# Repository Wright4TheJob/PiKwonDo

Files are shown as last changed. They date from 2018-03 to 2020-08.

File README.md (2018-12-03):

# PiKwonDo
A Raspberry Pi-based system for scoring TaeKwonDo sparring matches.

# Goals
The goal of this project is to create an inexpensive system for scoring TaeKwonDo sparring. This system is intended to be small and easily modified to suit the needs of individual Dojangs. The system is currently designed for electronic scoring manually triggered by corner judges.

Phase 1 of the judging system will use judge triggers connected by wires to the central controller. Phase 2 is intended to use wireless judge trigger systems or mobile phone connectivity.

While the system is designed to mimic expensive World TaeKwonDo-approved systems, it is not certified for official tournament use.

# Status


Bill of Materials:

The project is under alpha development. Software has been developed but has yet to be tested with the hardware. Electronics are designed for single-sided PCB routing and have all completed initial design but have not been tested yet. Cases are designed for 3D printing. Hardware and software folders have individual README files with more particular statuses and todo items.

All design files and software are provided "as-is." Any stable releases will be bundled for easy download, but this does not guarantee suitability for your particular setup.

# Software
The judging software and UI is written in python and QT. A dedicated thread scans the status of judge controller buttons. Game logic and UI are run as the primary thread.
<!--Wireless versions of the software may use Twisted to create a local server.-->

# Electronics
Controllers use shift registers to store and sequentially read out the values of the buttons in each controller. Judge controllers have 10 buttons and the timer controller has 5. PCBs are designed for single-side milling, with traces no smaller than 0.4mm and trace gaps of 0.3mm. Through-hole components are used for hand soldering and occasional jumper wires are used.

# Hardware
The system is designed and tested on a Raspberry Pi 3B+. Physical wiring uses phone jacks and standard 4-conductor phone cables for data communication to judging triggers. Cases are designed for 3D printing and modeled in Solidworks.
<!--Future iterations may investigate the viability of using the Raspberry Pi Zero W.-->

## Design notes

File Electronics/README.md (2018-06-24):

# Electronics
The PiKwonDo is made of four different electrical boards bundled into three unique and connected elements: the processing core, the PiKwonDoHAT, the timer control board, and the judge control board.

All circuits and PCBs are modeled in KiCAD. PCBs are minimal complexity necessary. Boards are intended to be single-sided and capable of being milled on a home circuit board router.

# Processing Core
The core processing unit of the PiKwonDo is a Raspberry Pi. The system is being tested on a Raspberry Pi 3B+.

# PiKwonDoHAT
The PiKwonDoHAT board mounts to the Raspberry Pi and provides the GPIO interface to the RJ12 ports and external boxes. This board contains no logic, simply provides an I/O adapter.

# Peripheral Boxes
All the peripheral boxes (timer and judge boxes), use shift registers to store the button states and sequentially report buttons states to the processor when requested. This method reduces the number of data lines to the central processor and de-couples the number of data lines from the number of buttons per peripheral.

An LED is lighted by the shift pin of the shift register and will illuminate whenever the central processor is querying the state of the buttons.

## Timer
The timer control board contains 5 buttons: three to control the round timing (Start, Pause, Reset), and two penalty buttons (Red and Blue). A single shift register is used to output the state of these 5 buttons.

## Judge
The judge box board contains 10 buttons corresponding to point values of 1 through 5 for both red and blue. Two shift registers passing data in series are used to store the values of all 10 buttons.

# Status
Circuit diagrams have been completed and initial PCB layout and trace routing is done.

## TODO
* Finalize button positions on timer controller.
* Finalize BOM and component selection.
* Update component footprints to reflect BOM.
* Update trace size and spacing to ensure manufacturability.

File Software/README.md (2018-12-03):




# Software
The PiKwonDo software uses two primary processing threads to control 1) game logic and GUI and 2) scanning buttons and driving GPIO data flow. Software is written in Python and uses PiQT5 for GUI elements.

# Dependencies
* PyQT5
* GPIO

# Installation
Delete the RPi folder in Software to direct the python installtion to the global GPIO library present on the Raspberry Pi. If testing or modifying the software on a desktop computer, the RPi folder mimics the GPIO library and allows the software to run.

# Startup
To start the PiKwonDo software, navigate to the Software folder in the terminal and launch the PyKwonDo.py file using Python 3:
```
$ python3 PyKwonDo.py
```

# Status
Initial software class structure and functionality are in place. Interpretation of the button states is currently rudimentary. GUI is functional.

# Documentation
All documentation is generated using Sphinx and deployed on GihubPages [here]( https://wright4thejob.github.io/PiKwonDo/build/html/index.html). New code commits with correct docstrings can update the documentation by running ```$ make html``` from PiKwonDo/Software/docs.

## TODO
* Add check for system parameters to allow non-Raspberry Pi code testing
* Complete GPIO scanning code and test with hardware.
* Unit test combinations of judge signals.
* Create automated installation script.

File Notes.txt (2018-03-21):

Notes:
Send judge signal over 3 bits using 8-3 binary encoder

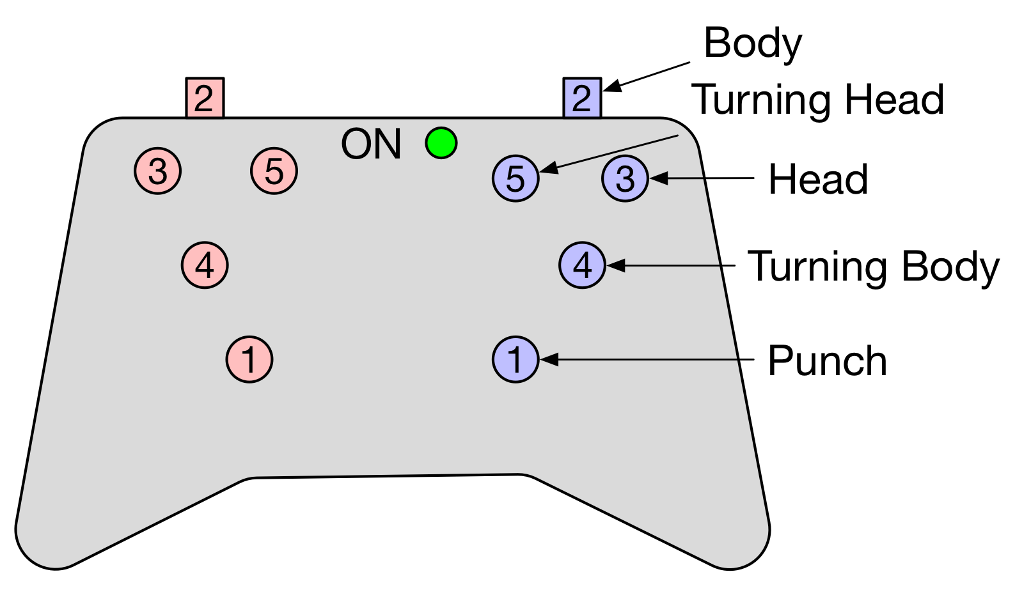
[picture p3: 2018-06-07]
Hardware/Judge Box/Button Layouts/ButtonDiagonal.png

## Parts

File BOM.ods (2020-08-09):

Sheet: PiKwonDo
 | System | Description | Part # | Manufacturer | Unit Price | Quantity | Total | Link
1 | Main Box | HAT |  | In-house | $11.55 | 1 | $11.55
2 |  | Raspberry Pi Zero |  |  | $5.00 | 1 | $5.00 | https://www.adafruit.com/product/3775?src=raspberrypi
3 |  | SD Card | 467-SDSDQAB-008G | SanDisk | $7.59 | 1 | $7.59 | https://www.mouser.com/ProductDetail/SanDisk/SDSDQAB-008G
4 |  | Power Cable | 1995 |  | $7.50 | 1 | $7.50 | https://www.adafruit.com/product/1995
5 |  | Header | 474-PRT-14275 |  | $0.95 | 1 | $0.95 | https://www.mouser.com/ProductDetail/SparkFun/PRT-14275
6 |  | Case Front | JudgeCaseFront | 3D Printed | $0.00 | 1 | $0.00
7 |  | Case Back | JudgeCaseBack | 3D Printed | $0.00 | 1 | $0.00
8 | Judging | Judge Box |  | In-house | $11.43 | 3 | $34.28
9 | Timing | Timer Box |  | In-house | $7.31 | 1 | $7.31
10 | Connection | Long Cable |  |  | $6.97 | 2 | $13.94
11 |  | Short Cable |  |  | $5.44 | 2 | $10.88
 |  |  |  |  |  | Total: | $99.00

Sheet: Judge Trigger Box
 | System | Description | Use | Manufacturer | Unit Price | Part # | Quantity | Total | Package | Link
1 | Buttons | Front Switch | Point values 1,3, 4, and 5 | Apem | $0.56 | MHPS2285V | 8 | $4.48 |  | https://www.mouser.com/ProductDetail/Apem/MHPS2285V?qs=sGAEpiMZZMvxtGF7dlGNpukRB9Cmt7zIMn5KtKQiwQo%3d
2 |  | Trigger Switch | 2 point trigger | E-Switch | $0.72 | LC1258OASP | 2 | $1.44 |  | https://www.mouser.com/ProductDetail/612-LC1258OASP
3 | PCB | PCB | Circuit board | JLCPCB | $0.83 |  | 1 | $0.83 |  | https://www.aliexpress.com/item/85042-Free-shipping-FR4-PCB-Single-Side-Copper-Clad-plate-DIY-PCB-Kit-Laminate-Circuit-Board/32658447865.html
4 | Memory | Shift Register | Data Storage | TI | $0.47 | SN74HC165N | 2 | $0.94 |  | https://www.mouser.com/ProductDetail/Texas-Instruments/SN74HC165N
5 | Diodes | Green LED | D1 (LED) | LiteOn | $0.12 | 859-LTL-4231N | 1 | $0.12 | T-1 3mm | https://www.mouser.com/ProductDetail/Lite-On/LTL-4231N
6 |  | Schottky Diode | D2 | Rectron | $0.10 | 583-FM5817 | 1 | $0.10 | SMA | https://www.mouser.com/ProductDetail/Rectron/FM5817-W
7 |  | Zener Diode | D3, D4, D5 | Rectron | $0.08 | 583-ZMM5232B | 3 | $0.24 | SOD-80C | https://www.mouser.com/ProductDetail/Rectron/ZMM5232B
8 | Capacitors | 470 pF Capacitor | C4, C5, C6 | Vishay | $0.08 | 885012208073 | 3 | $0.24 | SMD 1206 in | https://www.mouser.com/ProductDetail/Vishay-Vitramon/VJ0603A271JXACW1BC
9 |  | 1 uF Capacitor | C1, C2, C3 | Vishay | $0.10 | VJ1206Y105MXJTW1BC | 1 | $0.10 | SMD 1210 in | https://www.mouser.com/ProductDetail/Vishay-Vitramon/VJ1210V106ZXJTW1BC
10 | Resistors | 47 kOhm Resistor Network | RN1 and RN2 | Xicon | $0.25 | 264-47K-RC | 2 | $0.50 | SIP 6 | https://www.mouser.com/ProductDetail/Xicon/264-47K-RC?qs=sGAEpiMZZMvrmc6UYKmaNY74CgudZSh69je1RFoxttc%3d
11 |  | 470 Ohm Resistor | R2 and R3 | Vishay | $0.10 | 71-RCG1206470RJNEA | 2 | $0.20 | SMD 1206 in | https://www.mouser.com/ProductDetail/Vishay-Draloric/RCG1206470RJNEA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
12 |  | 10 Ohm Resistor | R4 | Ohmite | $0.10 | 588-AS12J10R0ET | 1 | $0.10 | SMD 1206 in | https://www.mouser.com/ProductDetail/Ohmite/AS12J10R0ET
13 |  | 68 Ohm Resistor | R1 | Vishay | $0.10 | 71-CRCW1206-68-E3 | 1 | $0.10 | SMD 1206 in | https://www.mouser.com/ProductDetail/Vishay/CRCW120668R0FKEA?qs=sGAEpiMZZMtlubZbdhIBIG0PxkvhMYcAMeHHOyUrHXU%3d
14 | I/O | RJ11 Port | Data Socket | Amphenol | $0.64 | RJE03-166-0110 | 1 | $0.64 |  | https://www.mouser.com/ProductDetail/Amphenol-Commercial-Products/RJE03-166-0110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
15 | Case | Case Front |  | 3D Printed | $1.02 | JudgeCaseFront | 1 | $1.02
16 |  | Case Back |  | 3D Printed | $0.00 | JudgeCaseBack | 1 | $0.00
17 |  | Button Cover |  | 3D Printed | $0.03 | ButtonCover | 8 | $0.22
18 |  | Trigger Cover |  | 3D Printed | $0.08 | TriggerCover | 2 | $0.15
 |  |  |  |  |  |  | Total: | $11.43

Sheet: Timer
 | System | Description | Schematic Number | Manufacturer | Unit Price | Part # Mouser | Part # Digikey | Quantity | Total | Package | Link
1 | Buttons | Front Switch | Point values 1,3, 4, and 5 | Apem | $0.56 | MHPS2285V |  | 5 | $2.80 |  | https://www.mouser.com/ProductDetail/Apem/MHPS2285V?qs=sGAEpiMZZMvxtGF7dlGNpukRB9Cmt7zIMn5KtKQiwQo%3d
2 | PCB | PCB | Circuit board | JLCPCB | $1.14 |  |  | 1 | $1.14 |  | https://www.mouser.com/ProductDetail/MG-Chemicals/521?qs=sGAEpiMZZMvAiOZiEFBkewg52Uv5EwqlDCdUaM0T7yM%3d
3 | Memory | Shift Register | U2 | TI | $0.47 | SN74HC165N |  | 1 | $0.47 |  | https://www.aliexpress.com/item/85042-Free-shipping-FR4-PCB-Single-Side-Copper-Clad-plate-DIY-PCB-Kit-Laminate-Circuit-Board/32658447865.html
4 | Diodes | Schottky Diode | D1 | Rectron | $0.10 | 583-FM5817 |  | 1 | $0.10 | DO-214AC | https://www.mouser.com/ProductDetail/Rectron/FM5817-W
5 |  | Green LED | D2 (LED) | LiteOn | $0.12 | 859-LTL-4231N |  | 1 | $0.12 | T-1 3mm | https://www.mouser.com/ProductDetail/Lite-On/LTL-4231N
6 |  | Zener Diode 5V | D3 | Rectron | $0.08 | 583-ZMM5232B |  | 1 | $0.08 | SOD-80C | https://www.mouser.com/ProductDetail/Rectron/ZMM5232B
7 |  | Zener Diode 3.3V | D4 | Nexperia | $0.19 |  | 1727-7754-1-ND | 1 | $0.19 | SOD-123-2 | https://www.mouser.com/ProductDetail/Diodes-Incorporated/MMSZ5226B-7-F
8 | Capacitors | 1 uF Capacitor | C1, C2 | Vishay | $0.13 | 77-VJ1206Y105MXJTBC |  | 2 | $0.26 | SMD 1206 in | https://www.mouser.com/ProductDetail/Vishay-Vitramon/VJ1206Y105MXJTW1BC
9 |  | 470 pF Capacitor | C3 | Wurth | $0.12 | 710-885012208073 |  | 3 | $0.36 | SMD 1210 in | https://www.mouser.com/ProductDetail/Wurth-Electronics/885012208073
10 | Resistors | 47 kOhm Resistor Network | RN1 | Xicon | $0.25 | 264-47K-RC |  | 1 | $0.25 | SIP 6 | https://www.mouser.com/ProductDetail/Xicon/264-47K-RC?qs=sGAEpiMZZMvrmc6UYKmaNY74CgudZSh69je1RFoxttc%3d
11 |  | 470 Ohm Resistor | R2-R4 | Vishay | $0.10 | 71-RCG1206470RJNEA |  | 3 | $0.30 | SMD 1206 in | https://www.mouser.com/ProductDetail/Vishay-Draloric/RCG1206470RJNEA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
12 |  | 10 Ohm Resistor | R5 | Ohmite | $0.10 |  | RNCP1206FTD10R0CT-ND | 1 | $0.10 | SMD 1206 in | https://www.mouser.com/ProductDetail/Ohmite/AS12J10R0ET
13 |  | 100 Ohm Resistor | R1 | TE | $0.10 | 667-ERJ-8ENF95R3V |  | 1 | $0.10 | SMD 1206 in | https://www.mouser.com/ProductDetail/TE-Connectivity-Holsworthy/CRGP1206F100R
14 | I/O | RJ11 Port | Data Socket | Molex | $0.78 | 538-95009-7641 |  | 1 | $0.78 |  | https://www.mouser.com/ProductDetail/Molex/95009-7641
 |  | Logic Level Shifter | U1 | Microtel | $0.12 | MIC5504-3.3YM5-TR |  | 1 | $0.12 | SC-70-5 or SOT-23-5 | https://www.mouser.com/ProductDetail/Microchip-Technology-Micrel/MIC5504-33YM5-TR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
15 | Case | Case Front |  | 3D Printed | $0.00 | JudgeCaseFront |  | 1 | $0.00
16 |  | Case Back |  | 3D Printed | $0.00 | JudgeCaseBack |  | 1 | $0.00
17 |  | Button Cover |  | 3D Printed | $0.03 | ButtonCover |  | 5 | $0.14
 |  |  |  |  |  |  |  | Total: | $7.31

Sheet: HAT
 | System | Description | Use | Manufacturer | Unit Price | Part # Mouser | Part # Digikey | Quantity | Total | Package | Link
1 |  | RJ11 Port | Data Socket | Amphenol | $0.64 | RJE03-166-0110 |  | 4 | $2.56 |  | https://www.mouser.com/ProductDetail/Amphenol-Commercial-Products/RJE03-166-0110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
2 |  | PCB | Circuit board | JLCPCB | $0.40 |  |  | 1 | $0.40 |  | https://www.aliexpress.com/item/5-pc-7-10CM-Single-Side-Circuit-Board-Copper-Clad-Plate-Laminate-Universal-PCB-Circuit-Board/32799673259.html
3 |  | Pin Header | CN1 |  | $2.55 | 517-929975-01-20 |  | 1 | $2.55 |  | https://www.mouser.com/ProductDetail/3M-Electronic-Solutions-Division/929975-01-20
4 | Capacitors | 10 nF Capacitor | C1-C4 | Wurth | $0.11 |  | 732-8093-1-ND | 4 | $0.44 | SMD 1206 in | https://www.mouser.com/ProductDetail/Wurth-Electronics/885012208026
5 |  | 470 pF Capacitor | C5-C12 | Wurth | $0.12 | 710-885012208073 |  | 8 | $0.96 | SMD 1206 in | https://www.mouser.com/ProductDetail/Wurth-Electronics/885012208073
6 | Resistor | 470 Ohm Resistor | R3, R6, R9, R12 | Vishay | $0.10 | 71-RCG1206470RJNEA |  | 4 | $0.40 | SMD 1206 in | https://www.mouser.com/ProductDetail/Vishay-Draloric/RCG1206470RJNEA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
 |  | 10 Ohm Resistor | R1,R2,R4,R5,R7,R8,R10,R11 | Ohmite | $0.10 |  | RNCP1206FTD10R0CT-ND | 8 | $0.80 | SMD 1206 in | https://www.mouser.com/ProductDetail/Ohmite/AS12J10R0ET
7 | Diodes | Zener Diode 5V | D1 | Rectron | $0.08 | 583-ZMM5232B |  | 1 | $0.08 | SOD-80C or SOD-323 | https://www.mouser.com/ProductDetail/Rectron/ZMM5232B
8 |  | Zener Diode 3.3V | D2-D9 | Diodes Inc. | $0.19 | 621-MMSZ5226B-F |  | 8 | $1.52 | SOD-123-2 | https://www.mouser.com/ProductDetail/Diodes-Incorporated/MMSZ5226B-7-F
9 |  | Buffer |  | TI | $0.46 | 595-SN74LV1T34DBVR |  | 4 | $1.84 | SC-70-5 or SOT-23-5 | https://www.mouser.com/ProductDetail/Texas-Instruments/SN74LV1T34DBVR
 |  |  |  |  |  |  |  | Total: | $11.55

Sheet: Printed Part Costs
Part | Weight [g] | Unit Cost | 1 kg Spool Cost: | $30.00
Button Cover | 0.93 | $0.03
Trigger Cover | 2.5 | $0.08
Judge Box Top | 34.08 | $1.02
Judge Box Bottom
Timer Box Top
Timer Box Bottom
Main Box Top
Main Box Bottom

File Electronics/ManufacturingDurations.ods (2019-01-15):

 | Duration | Quantity | Total
Leveling | 00:15:00 | 1 | 0.01042
PCB Traces | 00:27:20 | 1 | 0.01898
PCB Drilling | 00:16:10 | 1 | 0.01123
PCB Drill/Mill | 00:01:57 | 1 | 0.00135
PCB Edges | 00:05:00 | 1 | 0.00347
Tool Changes | 00:01:00 | 2 | 0.00139
Mill Total: |  |  | 67.45 | Minutes
Mill Time Cost: |  |  | $10.00 | $/hr
Mill Cost: |  |  | $11.24
Soldering: | 01:00:00 | 1 | 0.04167
Solder Total: |  |  | 60 | Minutes
Solder Time Cost: |  |  | $25.00 | $/hr
Solder Cost: |  |  | $25.00
Total Cost: |  |  | $36.24

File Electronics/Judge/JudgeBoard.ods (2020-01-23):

Reference | Quantity | Quant | Value | Footprint | Datasheet
C1 C2 C3 | 3 | 27 | 1uF | Capacitor_SMD:C_1206_3216Metric_Pad1.42x1.75mm_HandSolder
C4 C5 C6 | 3 | 27 | 470pF | Capacitor_SMD:C_1206_3216Metric_Pad1.42x1.75mm_HandSolder
D1 | 1 | 9 | LED | LED_THT:LED_D3.0mm_Spread
D2 | 1 | 9 | D_Schottky | Diodes_SMD:D_SMA_Handsoldering
D3 | 1 | 9 | 3.3V | Diode_SMD:D_1206_3216Metric_Pad1.42x1.75mm_HandSolder
D5 | 1 | 9 | 5V | Diodes_SMD:SOD-80C
J1 | 1 | 9 | RJ10 | Local_lib:RJ14 | ~
R1 R3 R5 | 3 | 27 | 470 | Resistor_SMD:R_1206_3216Metric_Pad1.42x1.75mm_HandSolder
R2 | 1 | 9 | 10 | Resistor_SMD:R_1206_3216Metric_Pad1.42x1.75mm_HandSolder
R4 | 1 | 9 | 100 | Resistor_SMD:R_1206_3216Metric_Pad1.42x1.75mm_HandSolder
RN1 RN2 | 2 | 18 | 47k | Resistor_THT:R_Array_SIP6
S1 | 1 | 9 | R1 | Buttons_Switches_THT:MHPS2285V
S10 | 1 | 9 | B5 | Buttons_Switches_THT:MHPS2285V
S2 | 1 | 9 | R3 | Buttons_Switches_THT:MHPS2285V
S3 | 1 | 9 | R5 | Buttons_Switches_THT:MHPS2285V
S4 | 1 | 9 | B2 | PiKwonDo:Switch-SPDT
S5 | 1 | 9 | B4 | Buttons_Switches_THT:MHPS2285V
S6 | 1 | 9 | R2 | PiKwonDo:Switch-SPDT
S7 | 1 | 9 | R4 | Buttons_Switches_THT:MHPS2285V
S8 | 1 | 9 | B1 | Buttons_Switches_THT:MHPS2285V
S9 | 1 | 9 | B3 | Buttons_Switches_THT:MHPS2285V
U1 U2 | 2 | 18 | 74HC165 | Housings_DIP:DIP-16_W7.62mm_LongPads
U3 | 1 | 9 | MIC5504-3.3YM5 | Package_TO_SOT_SMD:SOT-23-5 | http://ww1.microchip.com/downloads/en/DeviceDoc/MIC550X.pdf

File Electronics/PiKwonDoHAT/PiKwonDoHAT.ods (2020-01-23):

Reference | Quantity | Value | Footprint | Datasheet
C2 C1 C4 C3 | 4 | 10nF | Capacitor_SMD:C_1206_3216Metric_Pad1.42x1.75mm_HandSolder
C6 C5 C8 C7 C10 C9 C12 C11 | 8 | 470pF | Capacitor_SMD:C_1206_3216Metric_Pad1.42x1.75mm_HandSolder
D1 | 1 | 5V | Diodes_SMD:D_SOD-323_HandSoldering
D2 D3 D4 D5 D6 D7 D8 D9 | 8 | 3.3V | Diode_SMD:D_SOD-123
J1 J2 J3 J4 | 4 | RJ10 | Local_lib:RJ14 | ~
J5 | 1 | Conn_02x20_Odd_Even | Connector_PinSocket_2.54mm:PinSocket_2x20_P2.54mm_Vertical | ~
R1 R2 R5 R7 R10 R4 R8 R11 | 8 | 10 | Resistors_SMD:R_1206_HandSoldering
R3 R6 R9 R12 | 4 | 470 | Resistors_SMD:R_1206_HandSoldering
U1 U2 U3 U4 | 4 | 74LV1T34 | TO_SOT_Packages_SMD:SOT-23-5_HandSoldering

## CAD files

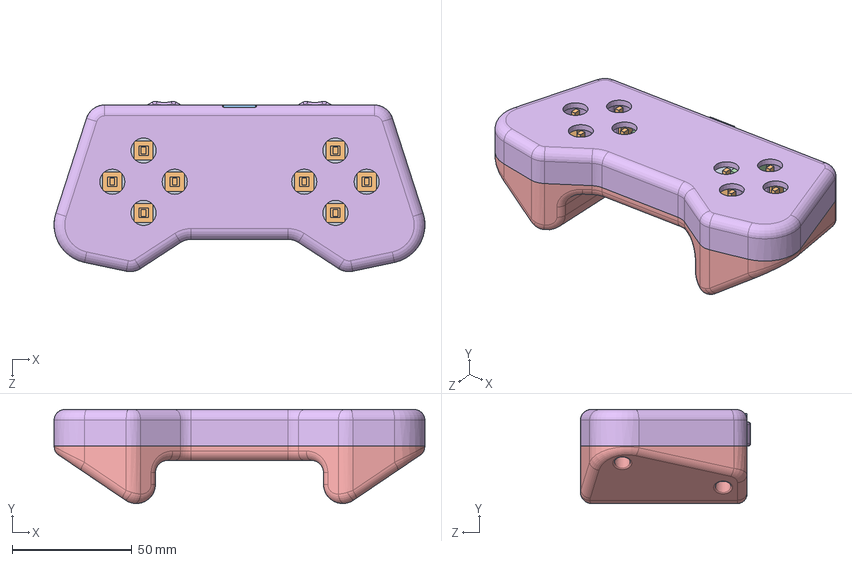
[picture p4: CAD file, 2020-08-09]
Hardware/Judge Box/JudgeController.SLDASM
154.6 x 39.2 x 71.0 mm
JudgePCB
PushButton x 8
RJ12Socket
TriggerButton x 2
JudgeEnclosureBack
JudgeEnclosureFront

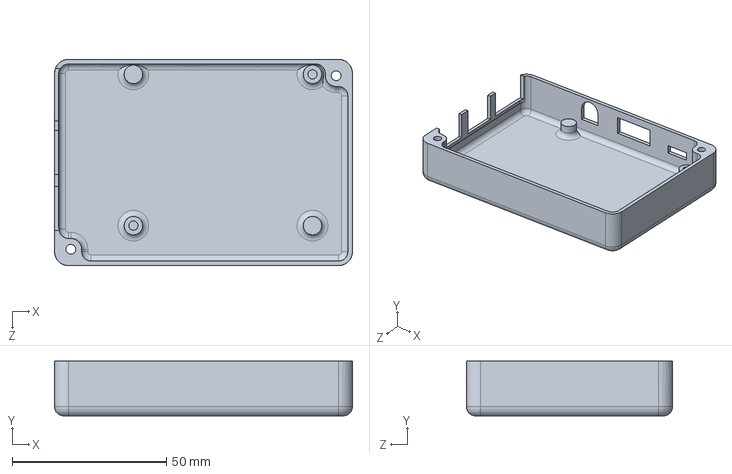
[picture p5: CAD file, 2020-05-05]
Hardware/Main Box/MainBoxCaseBottom.SLDPRT
96.5 x 17.8 x 66.8 mm

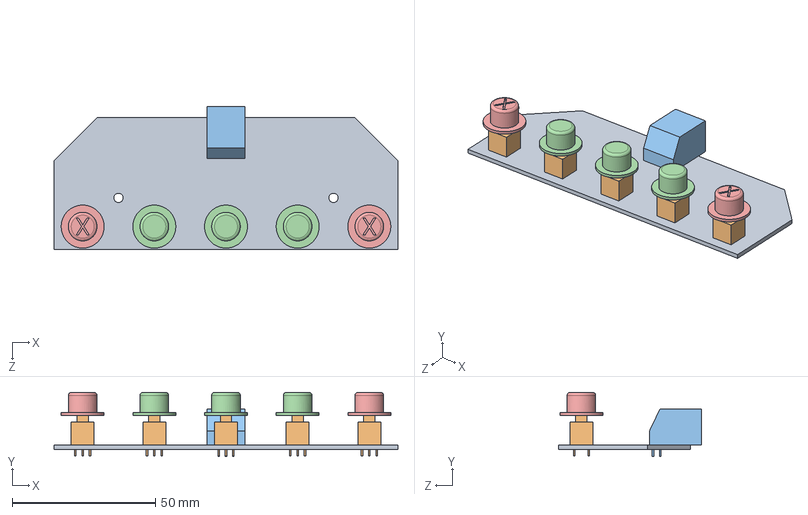
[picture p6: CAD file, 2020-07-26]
Hardware/Timer Box/TimerBoard.SLDASM
120.0 x 22.4 x 49.9 mm
TimerPCB
PushButton x 5
RJ12Socket
TopButtonCoverPlain x 3
TopButtonCoverX x 2

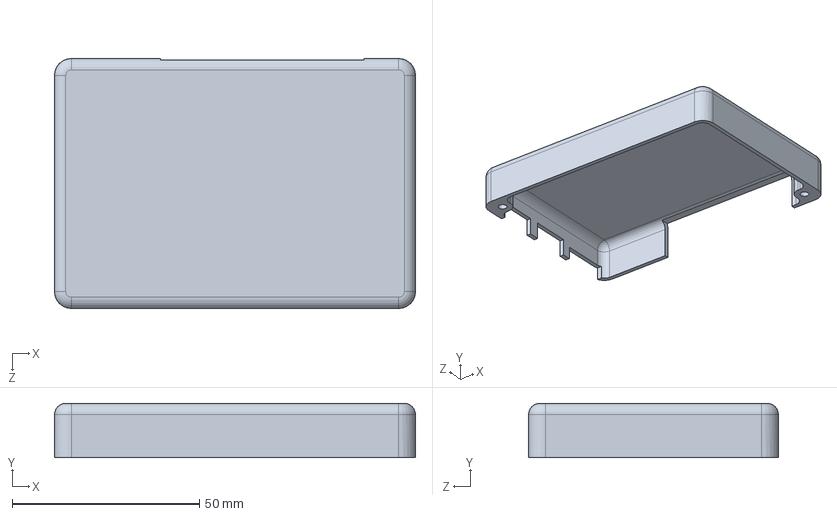
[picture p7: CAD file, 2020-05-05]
Hardware/Main Box/MainBoxCaseTop.SLDPRT
96.5 x 14.5 x 66.8 mm

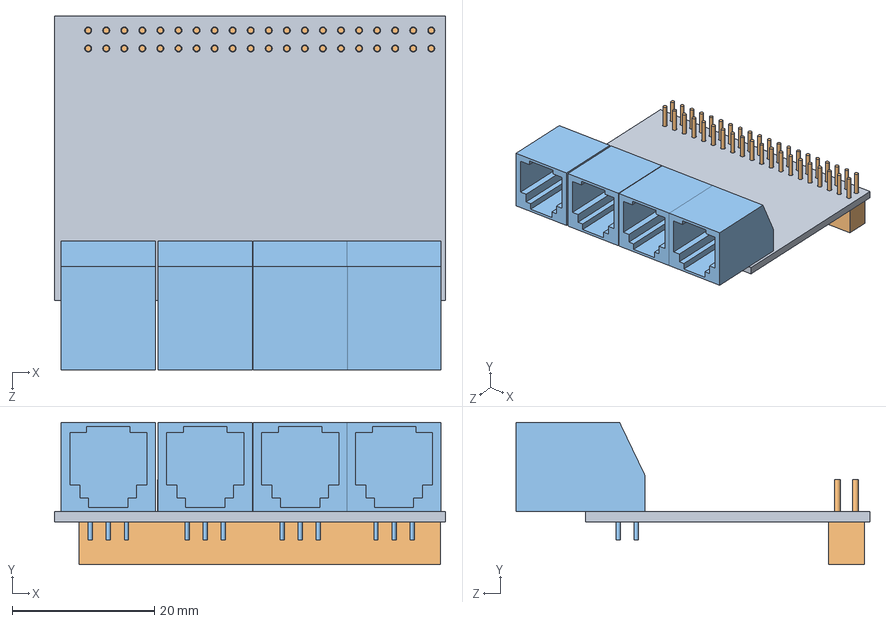
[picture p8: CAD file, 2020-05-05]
Hardware/Main Box/PiAdapterBoard.SLDASM
55.0 x 20.0 x 49.7 mm
HAT-PCB
PinHeader
RJ12Socket x 4

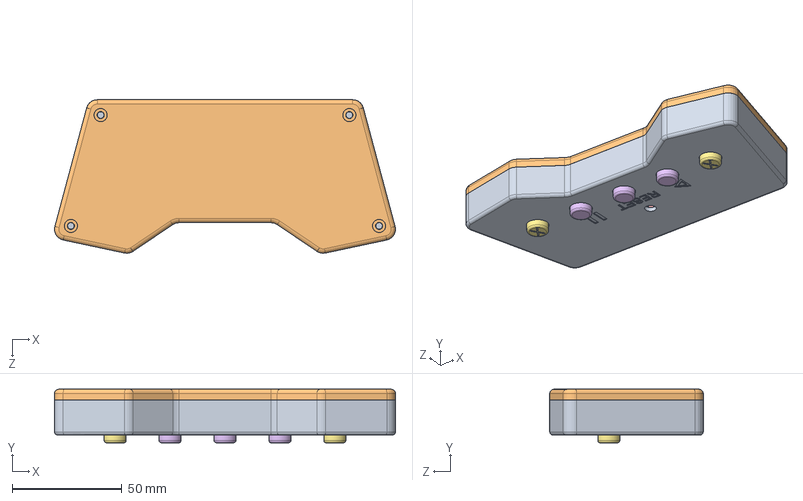
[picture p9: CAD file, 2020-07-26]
Hardware/Timer Box/TimerBox.SLDASM
155.3 x 24.4 x 69.9 mm
TimerBoxCaseTop
TimerPCB
PushButton x 5
RJ12Socket
TopButtonCoverPlain x 3
TopButtonCoverX x 2

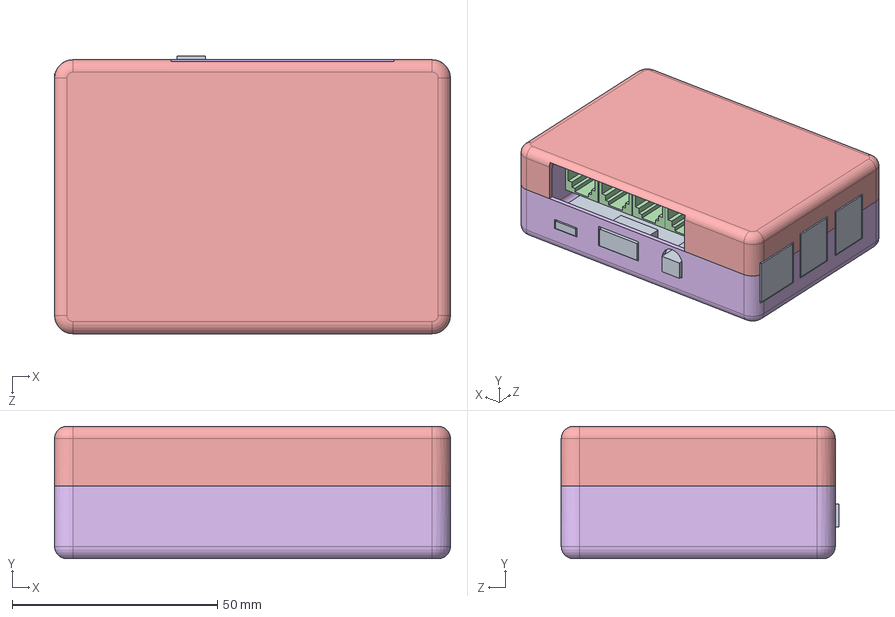
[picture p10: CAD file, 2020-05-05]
Hardware/Main Box/MainBox.SLDASM
96.5 x 32.3 x 67.7 mm
RaspberryPi3B+
HAT-PCB
PinHeader
RJ12Socket x 4
MainBoxCaseTop
MainBoxCaseBottom

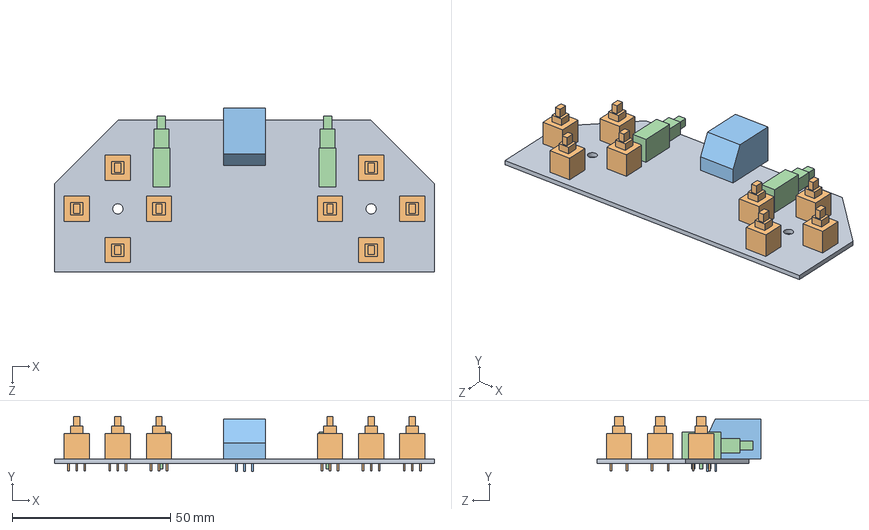
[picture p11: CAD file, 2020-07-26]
Hardware/Judge Box/JudgeBoard.SLDASM
120.0 x 17.4 x 51.9 mm
JudgePCB
PushButton x 8
RJ12Socket
TriggerButton x 2

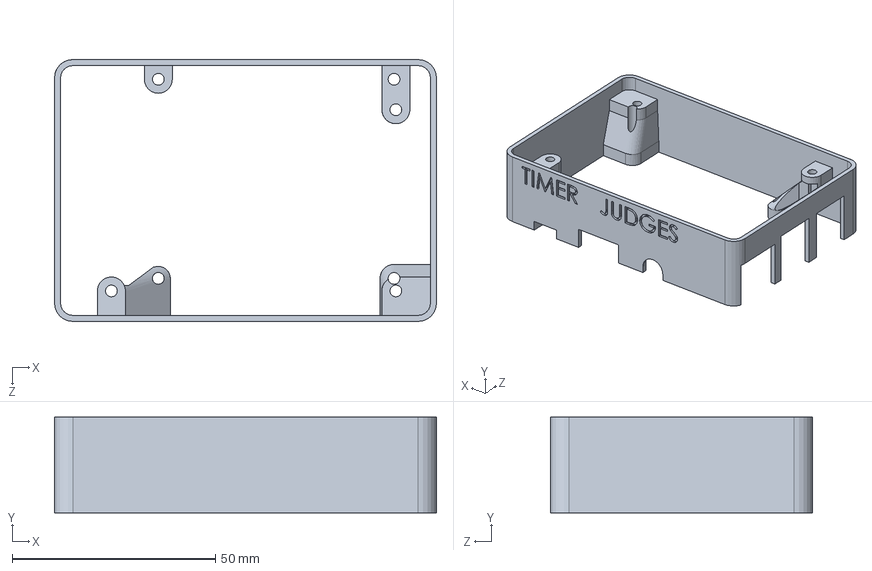
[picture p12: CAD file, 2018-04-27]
Hardware/Main Box/MainBoxCaseCenter.SLDPRT
94.0 x 23.5 x 64.4 mm

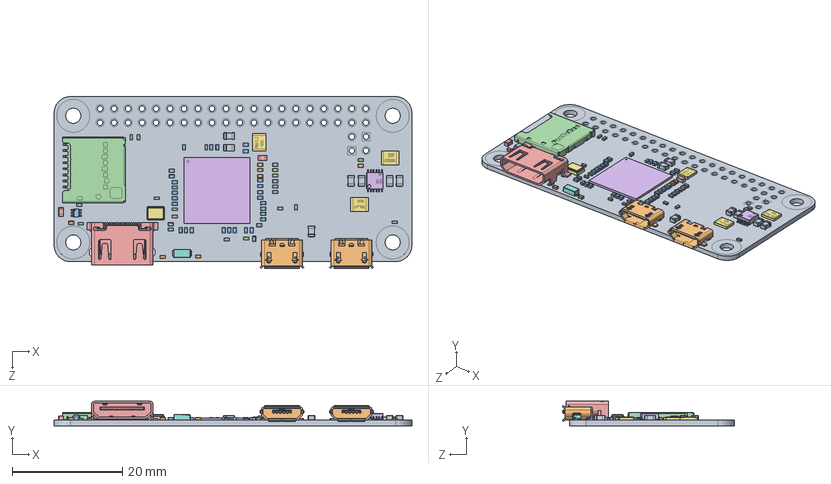
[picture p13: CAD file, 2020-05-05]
Hardware/Main Box/Raspberry Pi Zero/RapberryPiZero.SLDASM
65.0 x 4.45 x 31.2 mm
Raspberry_pizero_PCB
Micro USB_input_female (short)-SMT x 2
0204 - Capacitor x 34
0204- Resistor x 17
CAP-0306 x 2
Raspberry_pizero_BCM2835 with VC4
Crystal 3.4x2.4mm
32,768 Khz Crystal
0805- Capacitor x 7
0204 - Capacitor Brown x 8
6-Pin SOT
micro sd molex
hdmi type C
Voltage Regulator 3x3mm 12-Pin
1210 inductor x 3

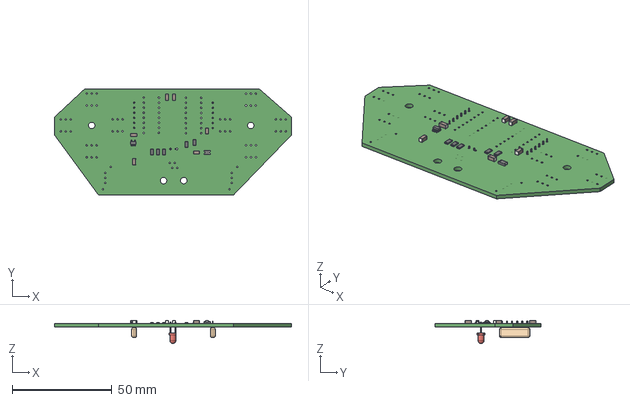
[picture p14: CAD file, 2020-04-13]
Electronics/Judge/JudgeBoard.step
119.0 x 53.0 x 11.6 mm

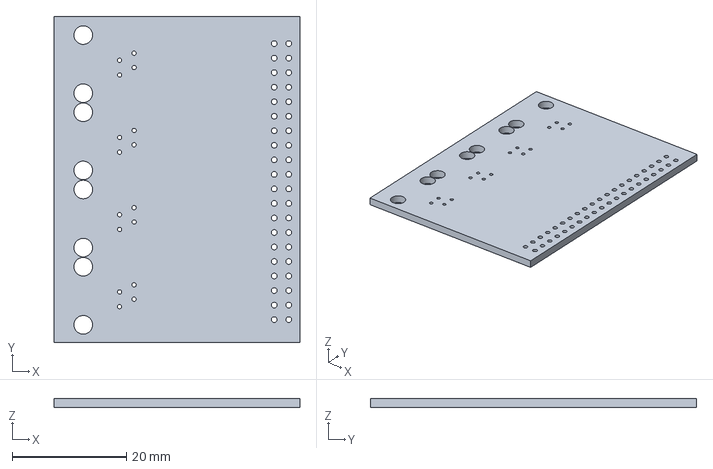
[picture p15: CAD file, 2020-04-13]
Electronics/PiKwonDoHAT/PiKwonDoHAT.step
43.0 x 57.0 x 1.60 mm

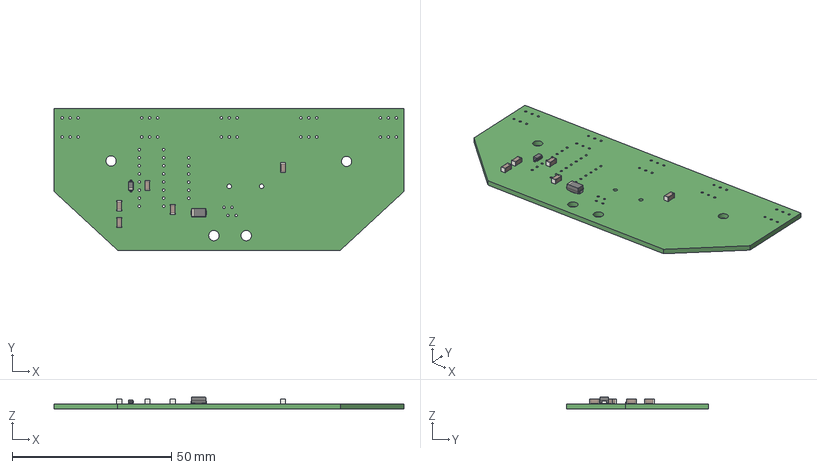
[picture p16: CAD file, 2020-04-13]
Electronics/Timer/Timer.step
110.0 x 44.5 x 3.87 mm

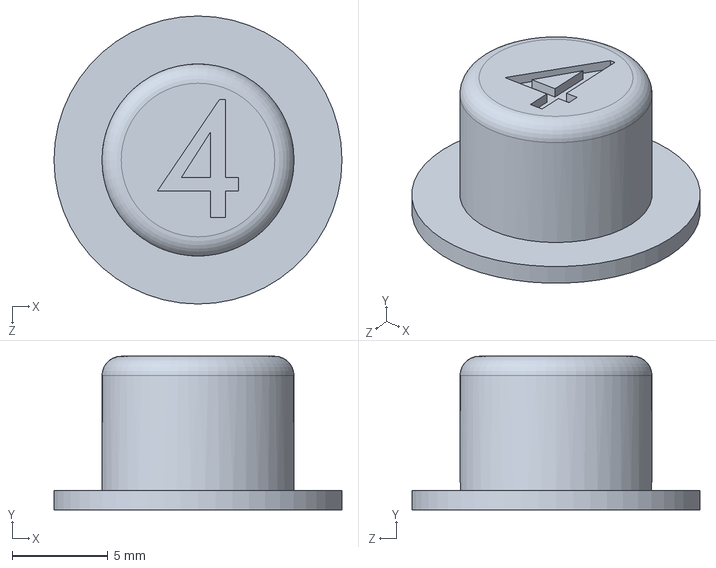
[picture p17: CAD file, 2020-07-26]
Hardware/Common Components/TopButtonCover4.SLDPRT
15.0 x 8.00 x 15.0 mm

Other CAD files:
Hardware/Main Box/Raspberry Pi Zero/32,768 Khz Crystal.SLDPRT
Hardware/Common Components/TriggerButton.SLDPRT
Hardware/Judge Box/JudgeEnclosureBackSolid.3MF
Hardware/Main Box/Raspberry Pi Zero/hdmi type C.SLDPRT
Hardware/Common Components/Dip8Socket.SLDPRT
Hardware/Common Components/PushButton.SLDPRT
Hardware/Common Components/RJ12Socket.SLDPRT
Hardware/Common Components/RaspberryPi3B+.SLDPRT
Hardware/Common Components/TopButtonCover1.SLDPRT
Hardware/Common Components/TopButtonCover1.STL
Hardware/Common Components/TopButtonCover2.SLDPRT
Hardware/Common Components/TopButtonCover3.SLDPRT
Hardware/Common Components/TopButtonCover3.STL
Hardware/Common Components/TopButtonCover4.STL
Hardware/Common Components/TopButtonCover5.SLDPRT
Hardware/Common Components/TopButtonCover5.STL
Hardware/Common Components/TopButtonCoverPlain.SLDPRT
Hardware/Common Components/TopButtonCoverX.SLDPRT
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

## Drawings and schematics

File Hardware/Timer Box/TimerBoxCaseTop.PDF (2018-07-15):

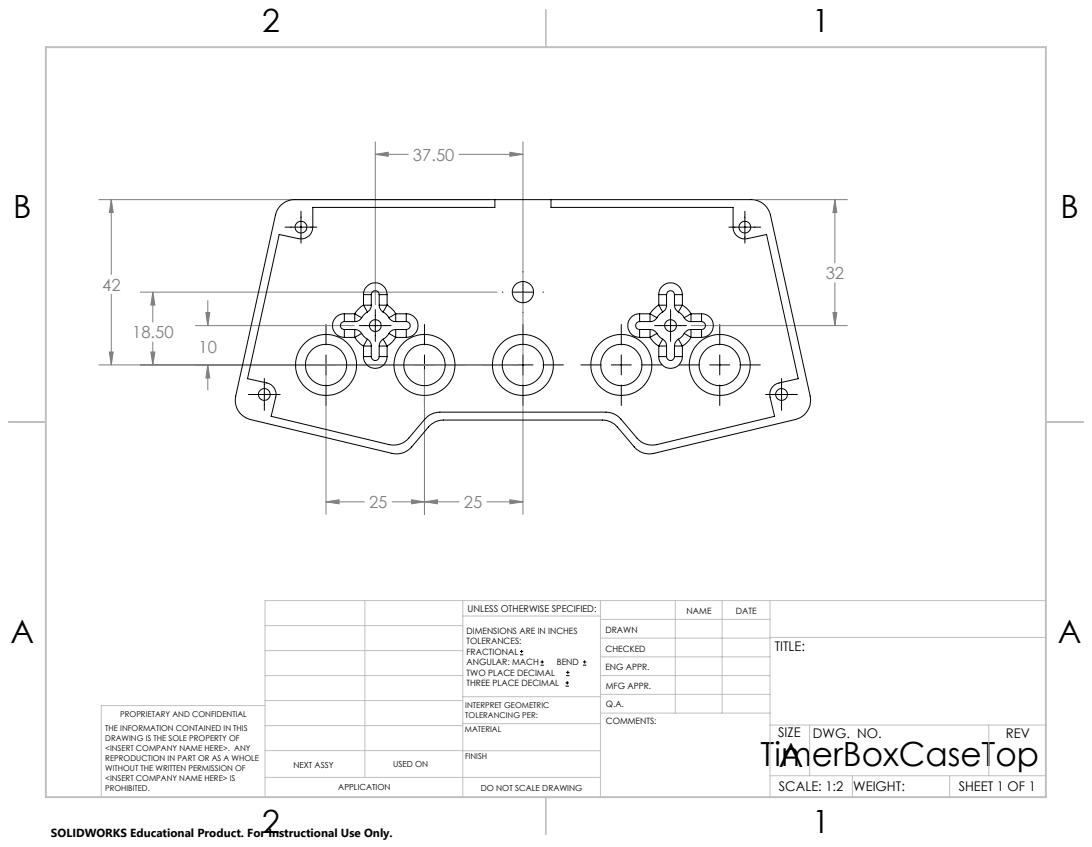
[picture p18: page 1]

UNLESS OTHERWISE SPECIFIED: | | NAME | DATE
DIMENSIONS ARE IN INCHES TOLERANCES: FRACTIONAL ANGULAR: MACH BEND TWO PLACE DECIMAL THREE PLACE DECIMAL | DRAWN

CHECKED | | | TITLE:

ENG APPR.
MFG APPR.

INTERPRET GEOMETRIC TOLERANCING PER: | Q.A.
MATERIAL | TimerBoxCaseTop | SIZE A | DWG. NO. | REV

PROPRIETARY AND CONFIDENTIAL
THE INFORMATION CONTAINED IN THIS
DRAWING IS THE SOLE PROPERTY OF
<INSERT COMPANY NAME HERE>. ANY
REPRODUCTION IN PART OR AS A WHOLE
WITHOUT THE WRITTEN PERMISSION OF
<INSERT COMPANY NAME HERE> IS
PROHIBITED.

NEXT ASSY | USED ON | FINISH

APPLICATION | DO NOT SCALE DRAWING | | SCALE: 1:2 | WEIGHT: | SHEET 1 OF 1

SOLIDWORKS Educational Product. For Instructional Use Only.

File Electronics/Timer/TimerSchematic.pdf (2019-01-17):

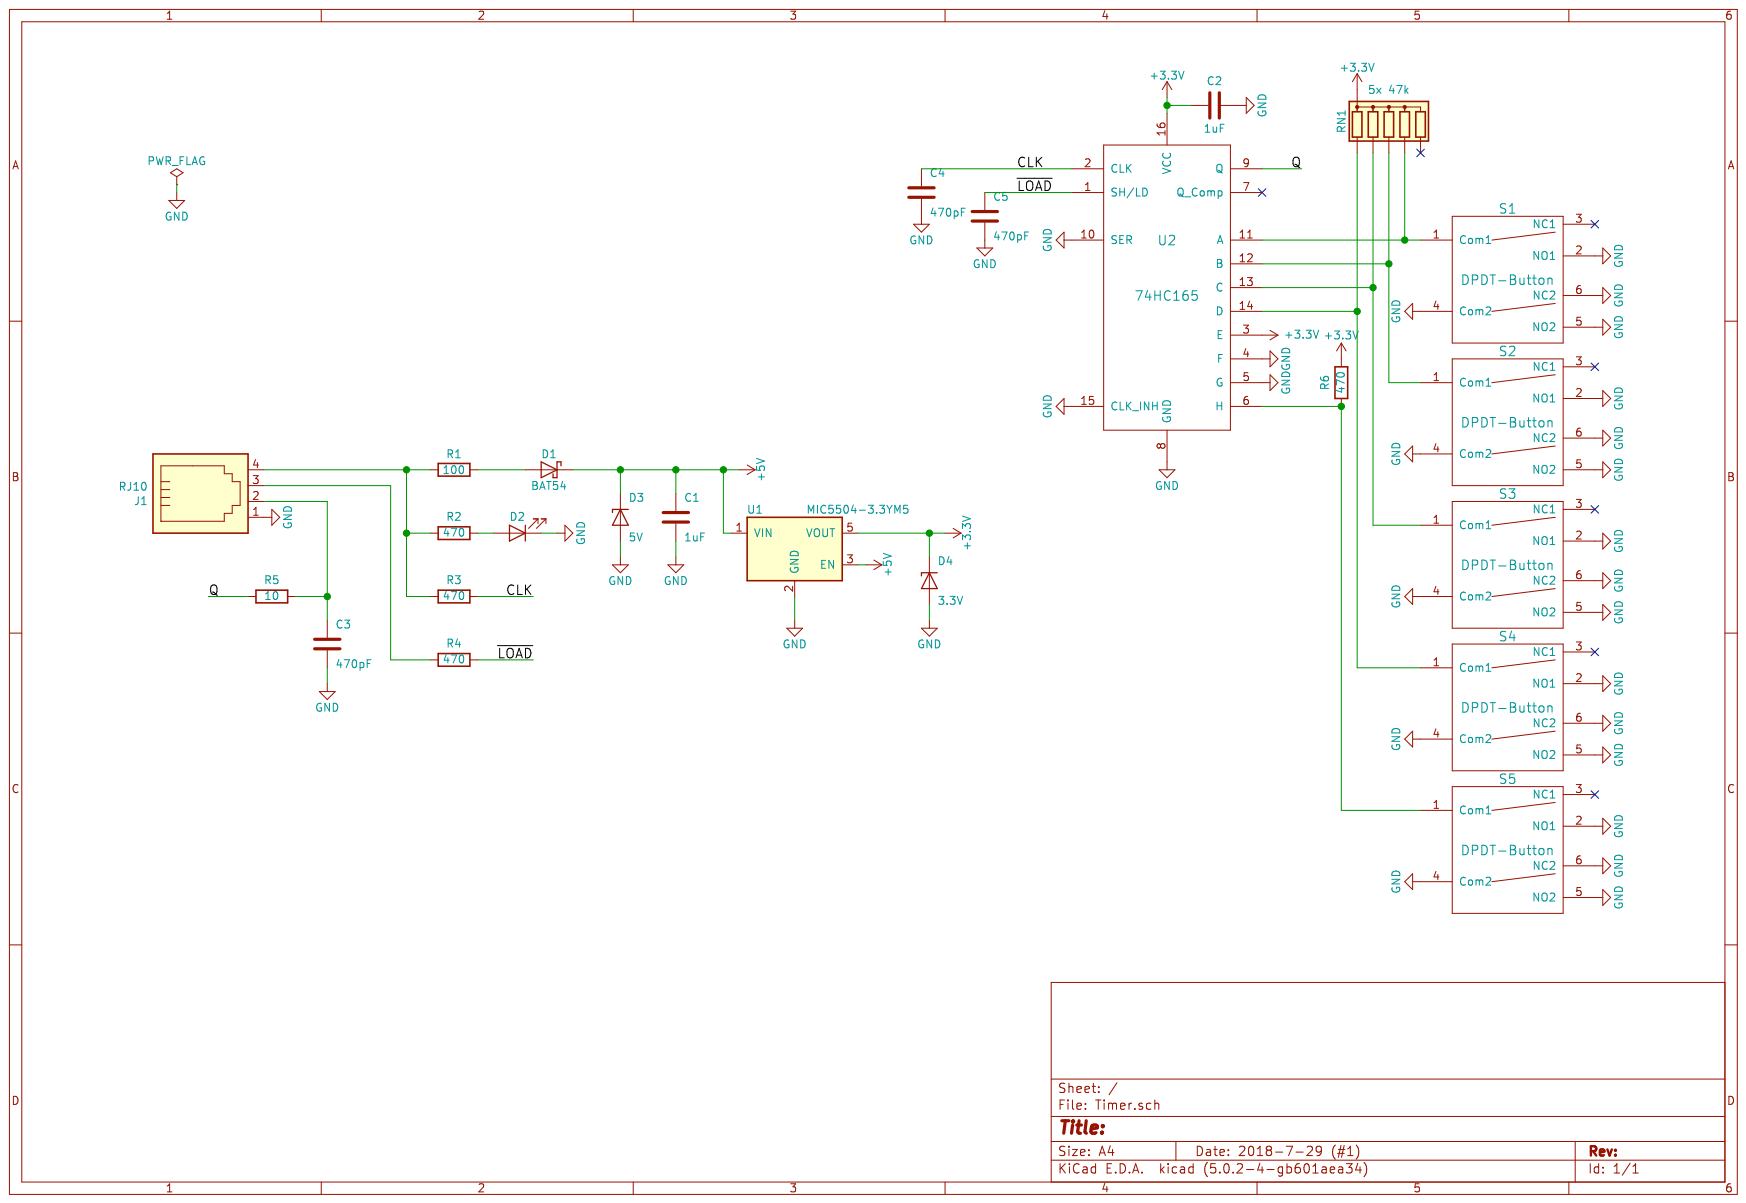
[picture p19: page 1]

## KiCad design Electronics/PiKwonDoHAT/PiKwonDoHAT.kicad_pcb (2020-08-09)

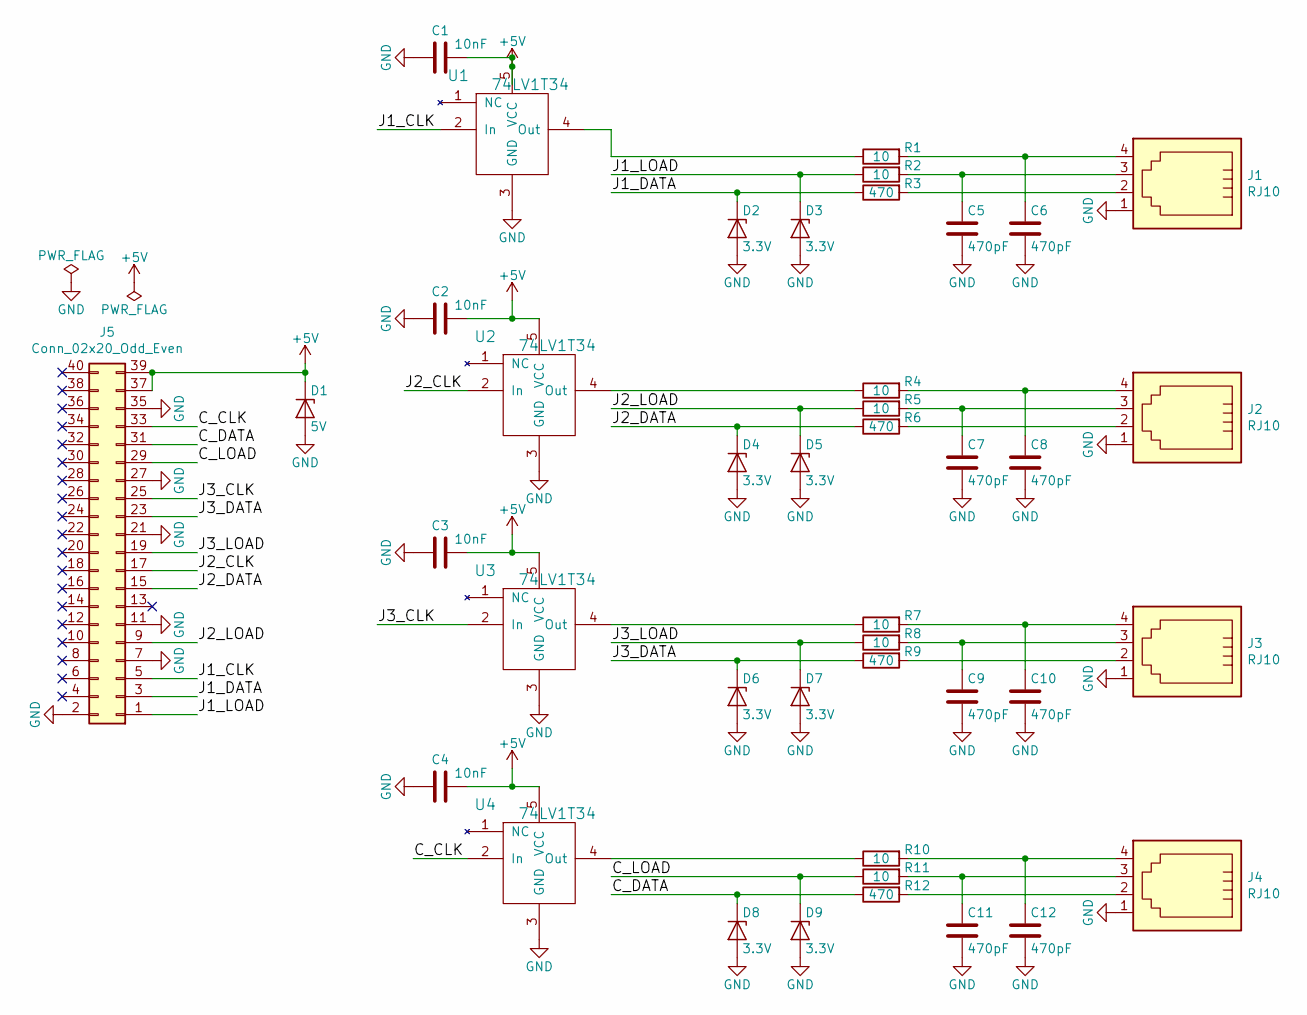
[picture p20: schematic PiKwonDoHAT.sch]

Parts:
C1, C2, C3, C4: 10nF; C_1206_3216Metric_Pad1.42x1.75mm_HandSolder
C5, C6, C7, C8, C9, C10, C11, C12: 470pF; C_1206_3216Metric_Pad1.42x1.75mm_HandSolder
D1: 5V; D_SOD-123
D2, D3, D4, D5, D6, D7, D8, D9: 3.3V; D_SOD-123
J1, J2, J3, J4: RJ10; RJ14
J5: Conn_02x20_Odd_Even; PinSocket_2x20_P2.54mm_Vertical
R1, R2, R4, R5, R7, R8, R10, R11: 10; R_1206_HandSoldering
R3, R6, R9, R12: 470; R_1206_HandSoldering
U1, U2, U3, U4: 74LV1T34; SOT-23-5_HandSoldering

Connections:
+5V: C1.1, C2.1, C3.1, C4.1, D1.1 (K), J5.37, J5.39, U1.5 (VCC), U2.5 (VCC), U3.5 (VCC), U4.5 (VCC)
/C_CLK: J5.33, U4.2 (In)
/C_DATA: D8.1 (K), J5.31, R12.1
/C_LOAD: D9.1 (K), J5.29, R11.1
/J1_CLK: J5.5, U1.2 (In)
/J1_DATA: D2.1 (K), J5.3, R3.1
/J1_LOAD: D3.1 (K), J5.1, R2.1
/J2_CLK: J5.17, U2.2 (In)
/J2_DATA: D4.1 (K), J5.15, R6.1
/J2_LOAD: D5.1 (K), J5.9, R5.1
/J3_CLK: J5.25, U3.2 (In)
/J3_DATA: D6.1 (K), J5.23, R9.1
/J3_LOAD: D7.1 (K), J5.19, R8.1
GND: C1.2, C2.2, C3.2, C4.2, C5.2, C6.2, C7.2, C8.2, C9.2, C10.2, C11.2, C12.2, D1.2 (A), D2.2 (A), D3.2 (A), D4.2 (A), D5.2 (A), D6.2 (A), D7.2 (A), D8.2 (A), D9.2 (A), J1.1, J2.1, J3.1, J4.1, J5.2, J5.7, J5.11, J5.21, J5.27, J5.35, U1.3 (GND), U2.3 (GND), U3.3 (GND), U4.3 (GND)
unnamed: C5.1, J1.3, R2.2
unnamed: C6.1, J1.4, R1.2
unnamed: C7.1, J2.3, R5.2
unnamed: C8.1, J2.4, R4.2
unnamed: C9.1, J3.3, R8.2
unnamed: C10.1, J3.4, R7.2
unnamed: C11.1, J4.3, R11.2
unnamed: C12.1, J4.4, R10.2
unnamed: J1.2, R3.2
unnamed: J2.2, R6.2
unnamed: J3.2, R9.2
unnamed: J4.2, R12.2
unnamed: R1.1, U1.4 (Out)
unnamed: R4.1, U2.4 (Out)
unnamed: R7.1, U3.4 (Out)
unnamed: R10.1, U4.4 (Out)

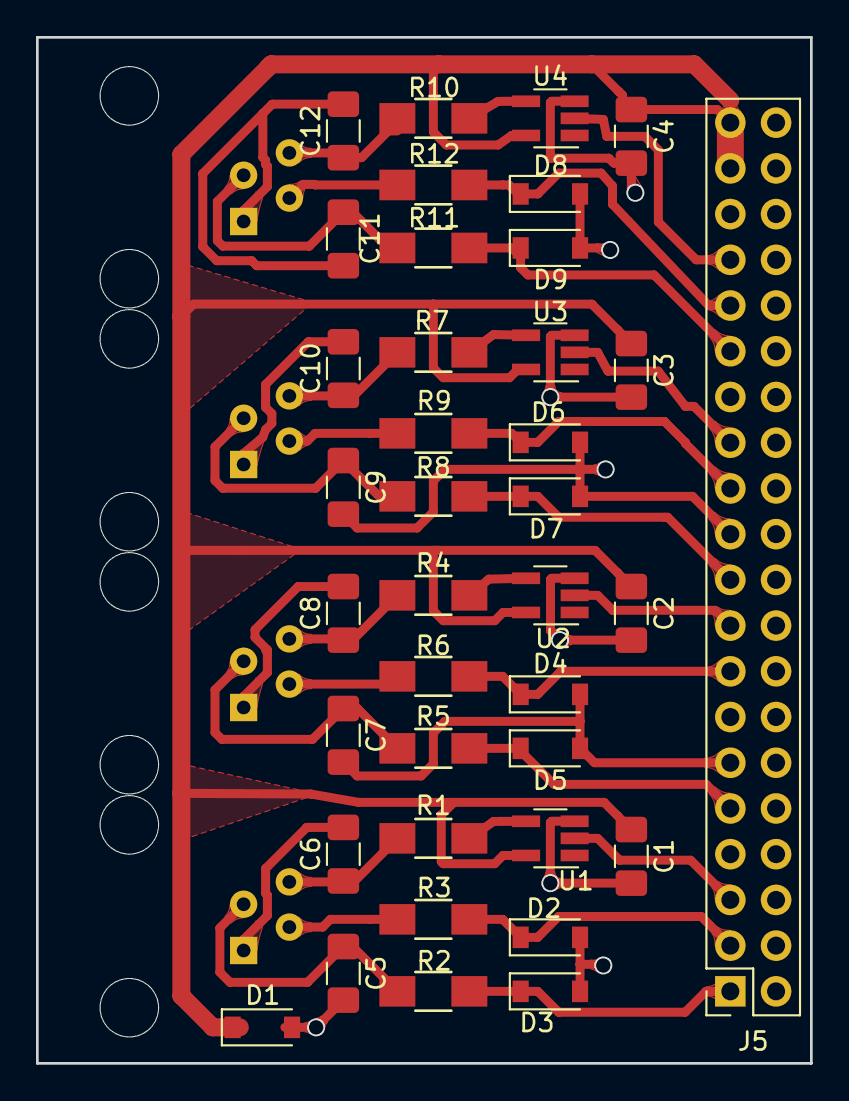
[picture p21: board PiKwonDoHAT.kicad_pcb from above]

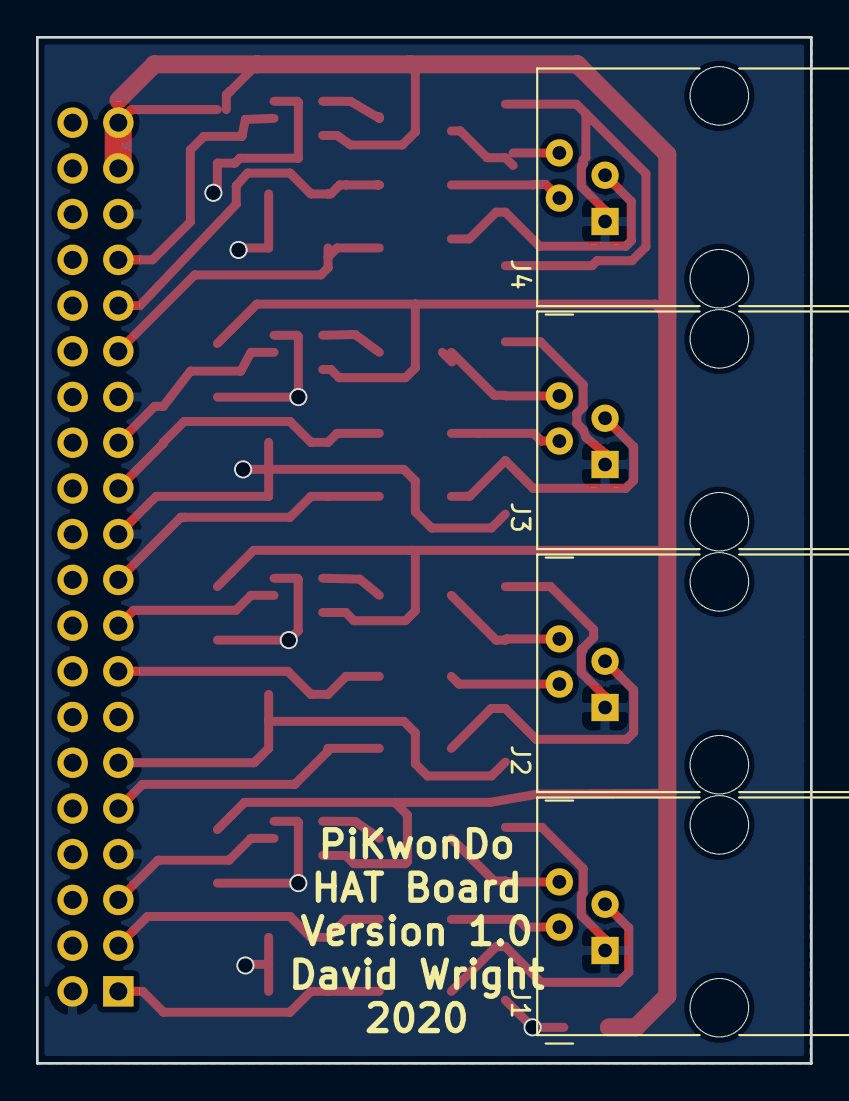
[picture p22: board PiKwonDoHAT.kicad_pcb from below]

Board: 2 copper layers, 43.0 x 57.0 mm, 42 parts (4 on the bottom side), 30 nets.

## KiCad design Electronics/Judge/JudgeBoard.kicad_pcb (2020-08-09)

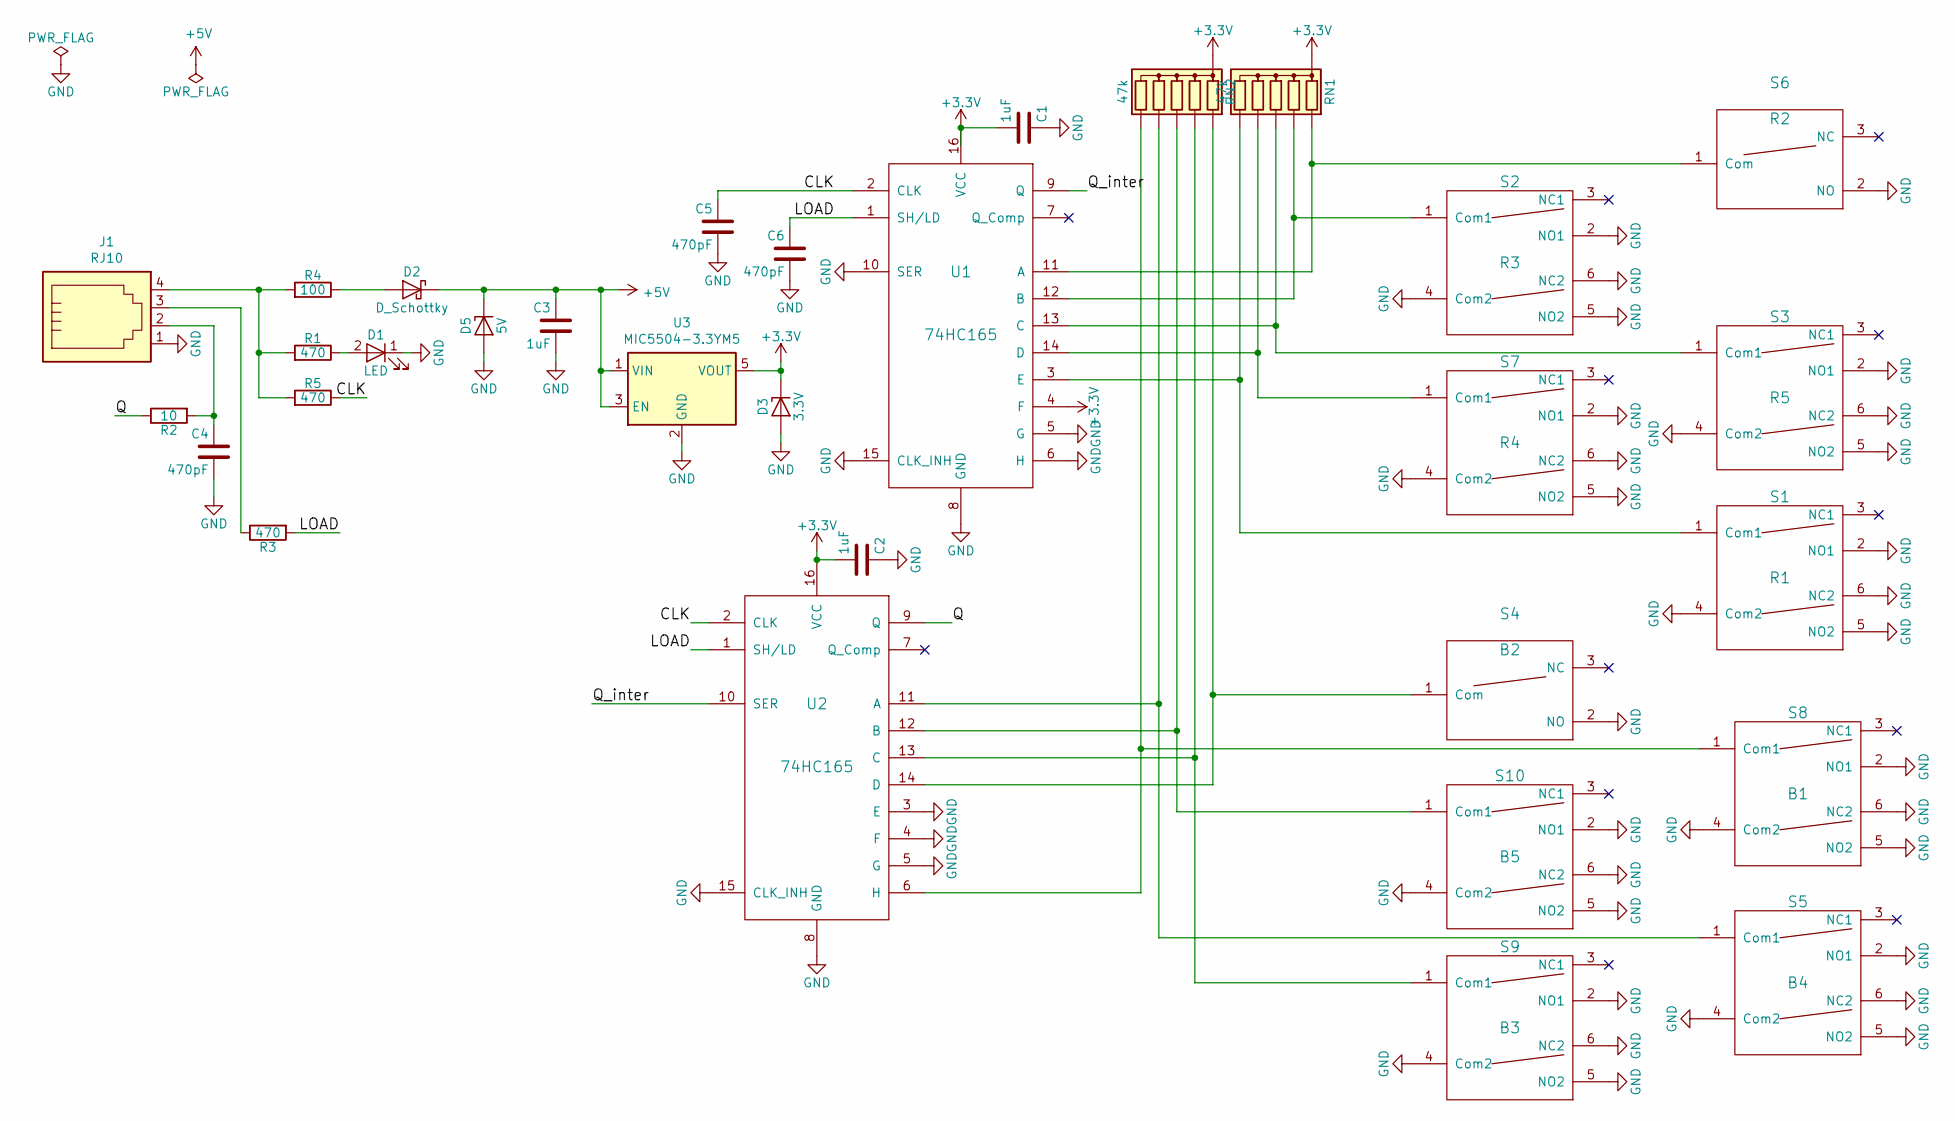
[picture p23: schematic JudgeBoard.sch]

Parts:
C1, C2, C3: 1uF; C_1206_3216Metric_Pad1.42x1.75mm_HandSolder
C4, C5, C6: 470pF; C_1206_3216Metric_Pad1.42x1.75mm_HandSolder
D1: LED; LED_D3.0mm_Spread
D2: D_Schottky; D_SMA_Handsoldering
D3: 3.3V; D_1206_3216Metric_Pad1.42x1.75mm_HandSolder
D5: 5V; SOD-80C
J1: RJ10; RJ14
R1, R3, R5: 470; R_1206_3216Metric_Pad1.42x1.75mm_HandSolder
R2: 10; R_1206_3216Metric_Pad1.42x1.75mm_HandSolder
R4: 100; R_1206_3216Metric_Pad1.42x1.75mm_HandSolder
RN1, RN2: 47k; R_Array_SIP6
S1: R1; MHPS2285V
S2: R3; MHPS2285V
S3: R5; MHPS2285V
S4: B2; Switch-SPDT
S5: B4; MHPS2285V
S6: R2; Switch-SPDT
S7: R4; MHPS2285V
S8: B1; MHPS2285V
S9: B3; MHPS2285V
S10: B5; MHPS2285V
U1, U2: 74HC165; DIP-16_W7.62mm_LongPads
U3: MIC5504-3.3YM5; SOT-23-5

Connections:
+3V3: C1.2, C2.2, D3.1 (K), RN1.1 (common), RN2.1 (common), U1.4 (F), U1.16 (VCC), U2.16 (VCC), U3.5 (VOUT)
+5V: C3.1, D2.1 (K), D5.1 (K), U3.1 (VIN), U3.3 (EN)
/CLK: C5.1, R5.1, U1.2 (CLK), U2.2 (CLK)
/LOAD: C6.1, R3.2, U1.1 (SH/LD), U2.1 (SH/LD)
/Q: R2.1, U2.9 (Q)
/Q_inter: U1.9 (Q), U2.10 (SER)
GND: C1.1, C2.1, C3.2, C4.2, C5.2, C6.2, D1.1 (K), D3.2 (A), D5.2 (A), J1.1, S1.2 (NO1), S1.4 (Com2), S1.5 (NO2), S1.6 (NC2), S2.2 (NO1), S2.4 (Com2), S2.5 (NO2), S2.6 (NC2), S3.2 (NO1), S3.4 (Com2), S3.5 (NO2), S3.6 (NC2), S4.2 (NO), S5.2 (NO1), S5.4 (Com2), S5.5 (NO2), S5.6 (NC2), S6.2 (NO), S7.2 (NO1), S7.4 (Com2), S7.5 (NO2), S7.6 (NC2), S8.2 (NO1), S8.4 (Com2), S8.5 (NO2), S8.6 (NC2), S9.2 (NO1), S9.4 (Com2), S9.5 (NO2), S9.6 (NC2), S10.2 (NO1), S10.4 (Com2), S10.5 (NO2), S10.6 (NC2), U1.5 (G), U1.6 (H), U1.8 (GND), U1.10 (SER), U1.15 (CLK_INH), U2.3 (E), U2.4 (F), U2.5 (G), U2.8 (GND), U2.15 (CLK_INH), U3.2 (GND)
unnamed: C4.1, J1.2, R2.2
unnamed: D1.2 (A), R1.1
unnamed: D2.2 (A), R4.1
unnamed: J1.3, R3.1
unnamed: J1.4, R1.2, R4.2, R5.2
unnamed: RN1.2 (R1), S6.1 (Com), U1.11 (A)
unnamed: RN1.3 (R2), S2.1 (Com1), U1.12 (B)
unnamed: RN1.4 (R3), S3.1 (Com1), U1.13 (C)
unnamed: RN1.5 (R4), S7.1 (Com1), U1.14 (D)
unnamed: RN1.6 (R5), S1.1 (Com1), U1.3 (E)
unnamed: RN2.2 (R1), S4.1 (Com), U2.14 (D)
unnamed: RN2.3 (R2), S9.1 (Com1), U2.13 (C)
unnamed: RN2.4 (R3), S10.1 (Com1), U2.12 (B)
unnamed: RN2.5 (R4), S5.1 (Com1), U2.11 (A)
unnamed: RN2.6 (R5), S8.1 (Com1), U2.6 (H)

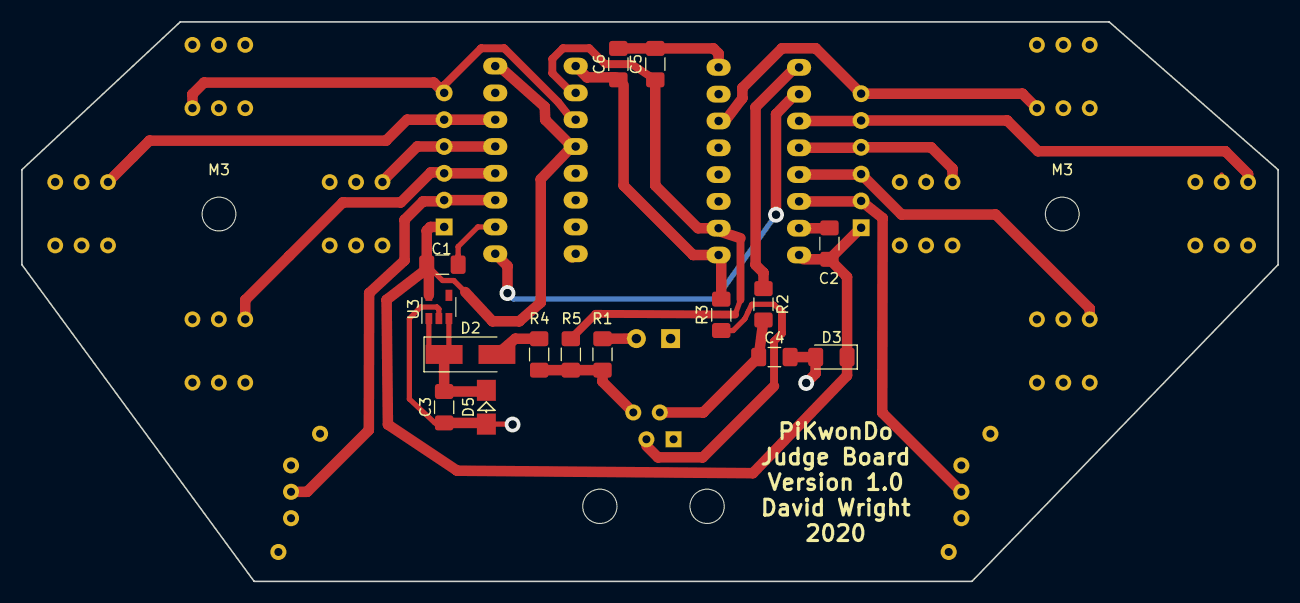
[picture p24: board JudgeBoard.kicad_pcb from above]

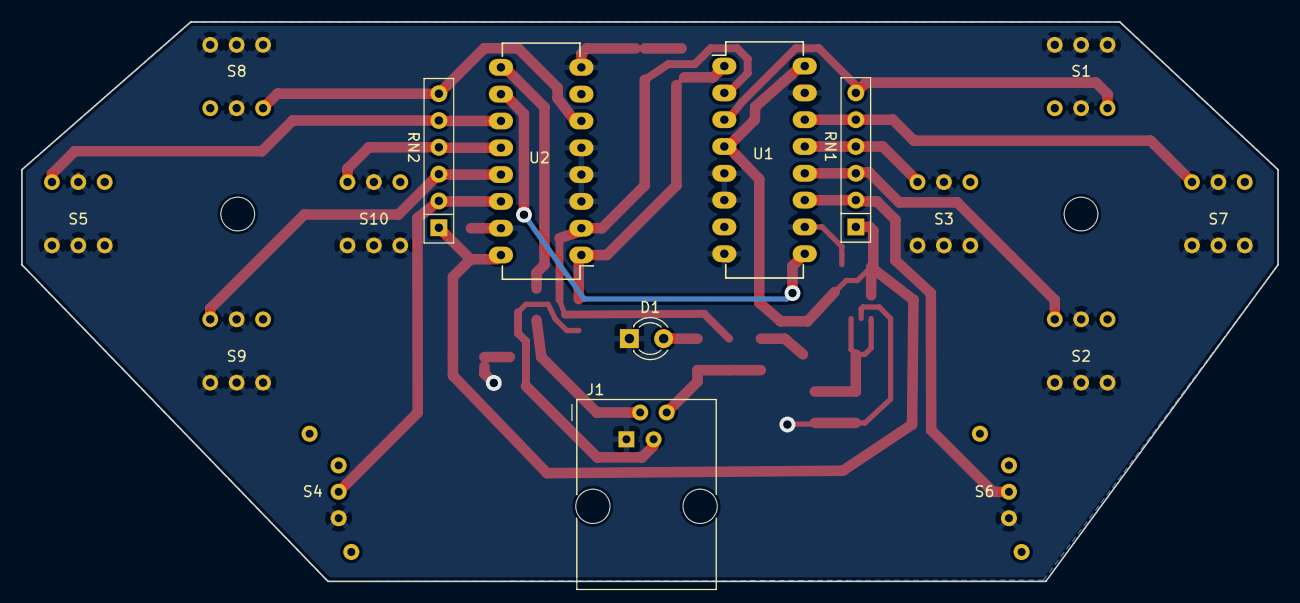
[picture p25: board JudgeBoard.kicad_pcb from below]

Board: 2 copper layers, 119.0 x 53.0 mm, 33 parts (16 on the bottom side), 22 nets.

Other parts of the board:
M3, M3#2: MountingHole_3.2mm_M3

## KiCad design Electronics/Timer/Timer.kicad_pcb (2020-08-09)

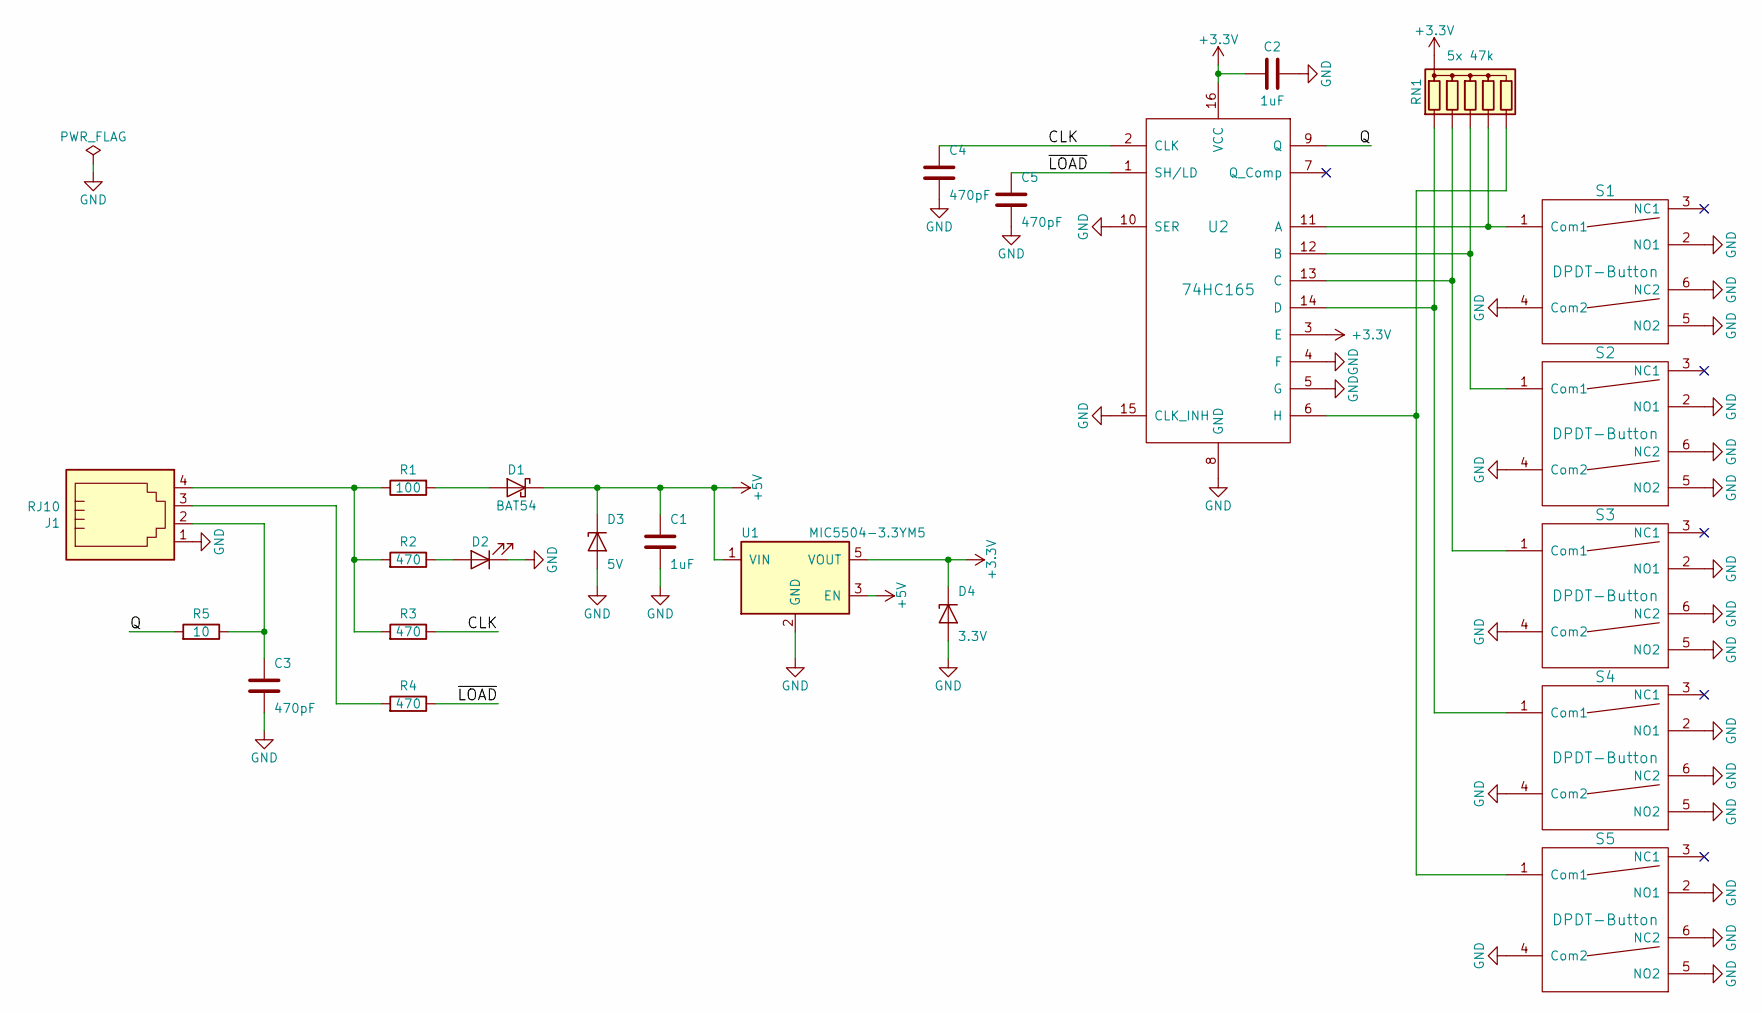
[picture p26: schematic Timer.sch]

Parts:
C1, C2: 1uF; C_1206_3216Metric_Pad1.42x1.75mm_HandSolder
C3, C4, C5: 470pF; C_1206_3216Metric_Pad1.42x1.75mm_HandSolder
D1: BAT54; D_SMA_Handsoldering
D2: LED; D_5W_P10.16mm_Horizontal
D3: 5V; D_SOD-323_HandSoldering
D4: 3.3V; D_SOD-123
J1: RJ10; RJ14
R1: 100; R_1206_HandSoldering
R2, R3, R4: 470; R_1206_HandSoldering
R5: 10; R_1206_HandSoldering
RN1: 5x 47k; R_Array_SIP6
S1, S2, S3, S4, S5: DPDT-Button; Switch-DPDT
U1: MIC5504-3.3YM5; SOT-23-5
U2: 74HC165; DIP-16_W7.62mm

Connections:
+3V3: C2.2, D4.1 (K), RN1.1 (common), U1.5 (VOUT), U2.3 (E), U2.16 (VCC)
+5V: C1.1, D1.1 (K), D3.1 (K), U1.1 (VIN), U1.3 (EN)
/CLK: C4.1, R3.1, U2.2 (CLK)
/Q: R5.2, U2.9 (Q)
/~LOAD~: C5.1, R4.1, U2.1 (SH/LD)
GND: C1.2, C2.1, C3.2, C4.2, C5.2, D2.1 (K), D3.2 (A), D4.2 (A), J1.1, S1.2 (NO1), S1.4 (Com2), S1.5 (NO2), S1.6 (NC2), S2.2 (NO1), S2.4 (Com2), S2.5 (NO2), S2.6 (NC2), S3.2 (NO1), S3.4 (Com2), S3.5 (NO2), S3.6 (NC2), S4.2 (NO1), S4.4 (Com2), S4.5 (NO2), S4.6 (NC2), S5.2 (NO1), S5.4 (Com2), S5.5 (NO2), S5.6 (NC2), U1.2 (GND), U2.4 (F), U2.5 (G), U2.8 (GND), U2.10 (SER), U2.15 (CLK_INH)
unnamed: C3.1, J1.2, R5.1
unnamed: D1.2 (A), R1.2
unnamed: D2.2 (A), R2.1
unnamed: J1.3, R4.2
unnamed: J1.4, R1.1, R2.2, R3.2
unnamed: RN1.2 (R1), S4.1 (Com1), U2.14 (D)
unnamed: RN1.3 (R2), S3.1 (Com1), U2.13 (C)
unnamed: RN1.4 (R3), S2.1 (Com1), U2.12 (B)
unnamed: RN1.5 (R4), S1.1 (Com1), U2.11 (A)
unnamed: RN1.6 (R5), S5.1 (Com1), U2.6 (H)

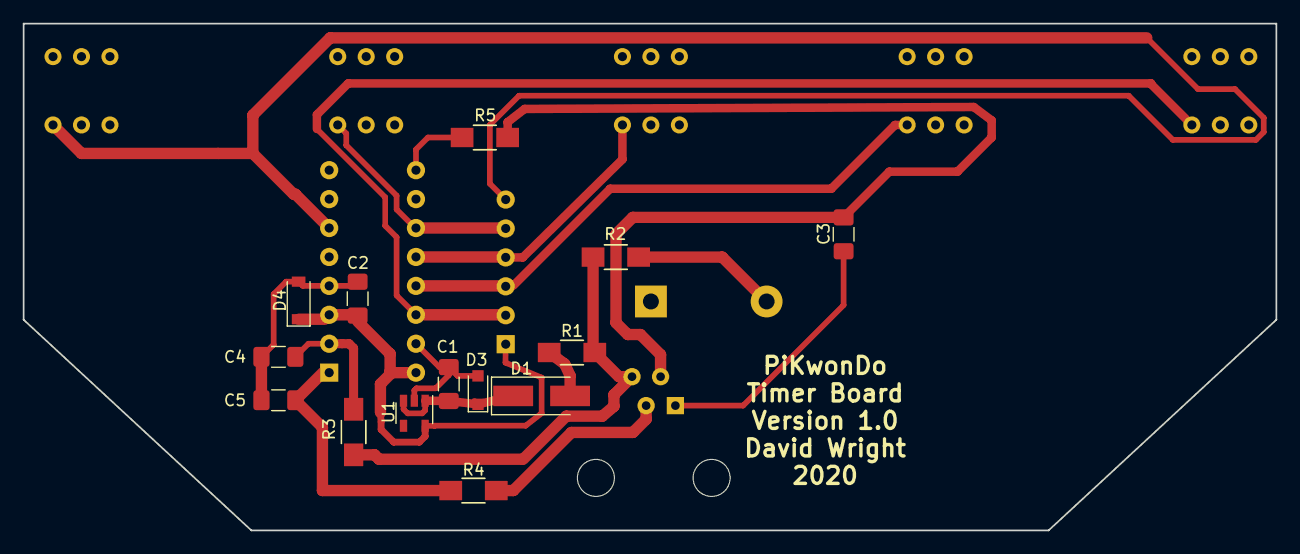
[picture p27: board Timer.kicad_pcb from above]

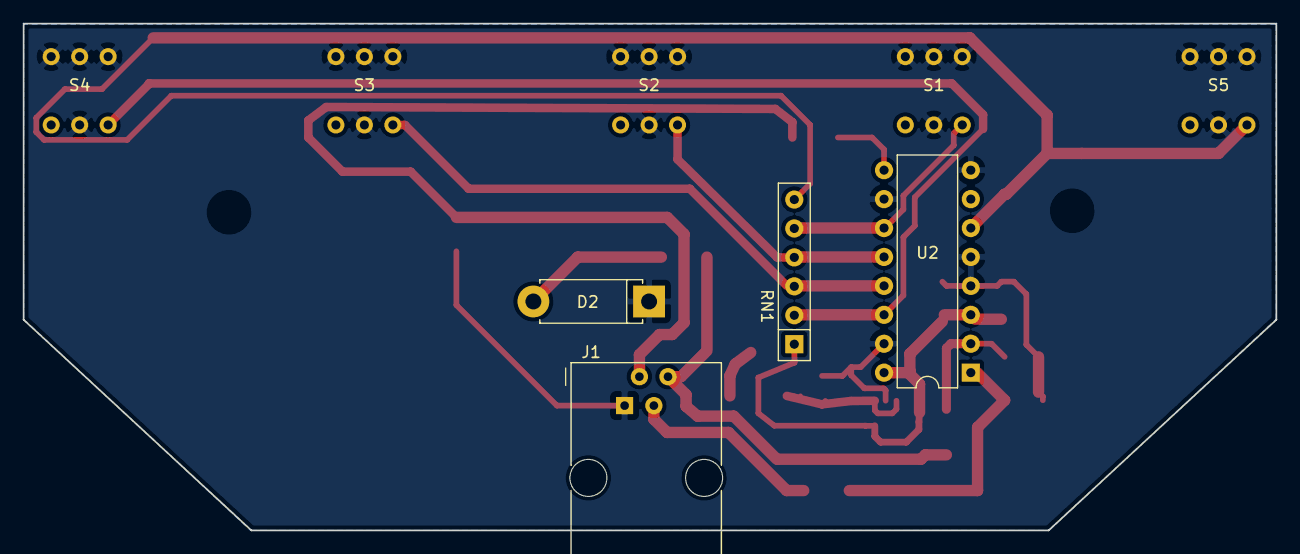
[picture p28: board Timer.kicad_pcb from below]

Board: 2 copper layers, 110.0 x 44.5 mm, 23 parts (9 on the bottom side), 16 nets.

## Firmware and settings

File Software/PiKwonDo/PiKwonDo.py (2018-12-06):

#!/bin/env/python
# David Wright
# Copyright 2017
# Written for Python 3.7

"""Primary game logic for PiKwonDo."""

# https://docs.python.org/3.7/library/queue.html

# Import
import time

from match import Match
import pkdtimer
from gui import FrontEndController
from utilities import UnknownFighterError
from utilities import OutOfRangeError
# Create match class
# Have game emit signal to indicate something changed
# Have GUI check game variables
# Program manager creates match and view controller instances, passes game to
# GUI, sets up hardware classes

# TODO: Blink timer LED when waiting for round to start? Require press of start
# button to begin each round, not just whole match


class PiKwonDo():
    """Primary game logic."""

    def __init__(self, create_gui=True):
        """Initialize variables and create game instance."""
        self.program_loaded = False
        # super(self.__class__, self).__init__()

        # Settings
        self.round_length = 90  # seconds
        self.time_left = self.round_length
        self.round_quantity = 2
        self.break_length = 30  # seconds
        self.max_gap_time = 1000  # ms
        # Initialize variables
        self.match = Match()
        self.match_running = False
        self.timer_running = False
        self.section_durations = [self.round_length]
        for _ in range(0, self.round_quantity-1):
            self.section_durations.append(self.break_length)
            self.section_durations.append(self.round_length)
        self.sections = len(self.section_durations)

        self.timer_thread = None

        if create_gui is True:
            self.gui_controller = FrontEndController(self)

        self.program_loaded = True

    def point_detected(self, person, point_value):
        """Respond to a point detected for a player."""
        if person == 0:
            self.red_point(point_value)
        elif person == 1:
            self.blue_point(point_value)
        else:
            raise UnknownFighterError(
                'code %i is not recognized in pointDetected' % (person))

    def penalty_detected(self, person):
        """Respond to a penalty detected for a player."""
        if person == 0:
            self.red_penalty()
        elif person == 1:
            self.blue_penalty()
        else:
            raise UnknownFighterError(
                'fighter code %i is not recognized penaltyDetected' % (person))

    def red_point(self, point_value):
        """Assign points to red player."""
        self.match.red_score += point_value
        # self.updateUI()

    def red_penalty(self):
        """Assign penalty to red player, and add a point to blue."""
        self.match.red_penalties += 1
        self.blue_point(1)
        # self.updateUI()

    def blue_point(self, point_value):
        """Assign points to blue player."""
        self.match.blue_score += point_value
        # self.updateUI()

    def blue_penalty(self):
        """Assign penalty to blue player, and add a point to red."""
        self.match.blue_penalties += 1
        self.red_point(1)
        # self.updateUI()

    def start_match(self):
        """Begin match timer and round tracking."""
        if self.match_running is False:
            self.match.current_section = 1
            self.start_round()
        else:
            self.resume_round()

    def start_round(self):
        """Begin round timer and incremement round."""
        if self.timer_running is False:
            # Timer Thread
            self.timer_thread = pkdtimer.TimerThread(
                self.section_durations[self.match.current_section-1])
            # Connect to emitted signals
            # self.timerThread.timerTicked.connect(self.timerTicked)
            # self.timerThread.timerDone.connect(self.timerDone)
            # Start the thread
            self.timer_thread.start()
        self.match_running = True
        self.timer_running = True

    def pause_round(self):
        """Save current time on round timer and terminate timer thread."""
        if self.timer_running is True:
            self.timer_thread.terminate()
        self.timer_running = False

    def resume_round(self):
        """Initialize new timer with remaining time."""
        if self.timer_running is False:
            self.timer_thread = pkdtimer.TimerThread(self.time_left)
            # Connect to emitted signals
            # self.timerThread.timerTicked.connect(self.timerTicked)
            # self.timerThread.timerDone.connect(self.timerDone)
            self.timer_thread.start()
        self.timer_running = True

    def reset_round(self):
        """Set points, penalties, and time to zero."""
        self.match = Match()
        self.time_left = self.round_length
        if self.timer_running is True:
            self.timer_thread.terminate()
        # self.updateUI()
        self.timer_running = False
        self.match_running = False

    def timer_ticked(self, new_time):
        """Save new time to match."""
        self.time_left = new_time
        # self.updateUI()

    def timer_done(self):
        """Respond to timer reading end, either end match or round."""
        # self.timerThread.terminate()
        self.timer_running = False
        self.time_left = 0
        # self.update()
        time.sleep(1)
        if self.match.current_section < self.sections:
            self.match.current_section += 1
            # TODO:Wait for manual trigger for start of next section?
            self.start_round()
        elif self.match.current_section == self.sections:
            self.match_running = False
        else:
            raise OutOfRangeError(
                'number is out of range (must be less than 10)')


def main():
    """Inializes game."""
    PiKwonDo()


if __name__ == '__main__':
    main()

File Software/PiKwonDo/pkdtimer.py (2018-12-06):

#!/bin/env/python
# David Wright
# Copyright 2017
# Written for Python 3.5.2
"""A set of timers for round control and evaluation."""
# Timer.py
# import datetime
import time
# import traceback
# import sys
import threading


class TimerThread():
    """Simple egg timer that emits a signal each second until done."""

    def __init__(self, duration, interval=1):
        """Establish duration, end time, and break off new thread."""
        self._start_time = time.monotonic()
        self.end_time = self._start_time + duration
        # print("Starting timer with %i seconds" % (duration))
        self.interval = interval
        self.is_done = threading.Event()

    def start(self):
        """Start the first tick of the timer."""
        self._tick()

    def tick(self):
        """Emit output on timer tick."""

    def done(self):
        """Emit output when timer finishes."""

    def _tick(self):
        """Perform actions to make timer tick."""
        remaining = self.end_time - time.monotonic()
        next_interval = min(remaining, self.interval)
        next_fn = self._tick if remaining > self.interval else self._done
        timer = threading.Timer(next_interval, next_fn)
        timer.start()
        self.tick()

    def _done(self):
        """Perform actions to close timer thread."""
        self.is_done.set()
        self.done()

    def current_time(self):
        """Calculate current timer time remaining."""
        return time.monotonic() - self._start_time

    def wait_until_done(self, timeout=None):
        """Idle the thread when not in use."""
        self.is_done.wait(timeout=timeout)

    def terminate(self):
        """Clean up thread upon close."""

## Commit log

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2018-03-30 Fixed bug in current time function. Added disqualification check.
    [PiKwonDo.py]
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2018-04-05 Added Raspberry Pi components to BOM
    [BOM.ods]
2018-04-11 Added Raspberry Pi source, updated switch model
    [BOM.ods]
2018-04-15 Initial models.
    Modeled proto board and push button.
    [ProtoBoard.SLDPRT, PushButton.SLDPRT, TopButtonCover.SLDPRT]
2018-04-19 Updated Judge Case
    Added DIP Socket, RJ12 Socket, Case Bottom. Positioned top buttons.
    [Dip8Socket.SLDPRT, JudgeBox.SLDASM, JudgeBoxBottom.SLDPRT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]
2018-04-20 Main Case, Trigger Button
    [JudgeBox.SLDASM, MainBox.SLDASM, MainBoxCaseCenter.SLDPRT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]
2018-04-21 Initial Main Box completed
    [MainBox.SLDASM, MainBoxCaseBottom.SLDPRT, MainBoxCaseBottom.STL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]
2018-04-22 Created Timer Case
    Laid out timer board components without LEDs, created both case sides.
    [MainBox.SLDASM, MainBoxCaseBottom.SLDPRT, MainBoxCaseBottom.STL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]
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2018-04-22 Initial Judge Case model
    [JudgeBoard.SLDASM, JudgeBox.SLDASM, JudgeBoxBottom.SLDPRT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]
2018-04-23 Refactored Main Box, added STLs.
    [MainBox.SLDASM, MainBoxCaseBottom.SLDPRT, MainBoxCaseBottom.STL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]
2018-04-25 Main Box model tweaks
    Fixed a collision in Main Box Center, updated interferance fit tolerances and text.
    [MainBox.SLDASM, MainBoxCaseBottom.SLDPRT, MainBoxCaseBottom.STL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]
2018-04-25 Updated Timer Box, exported STLs.
    [MainBox.SLDASM, MainBoxCaseCenter.SLDPRT, TimerBoard.SLDASM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]
2018-04-25 Updated Judge Box
    Moved components and avoided collisions.
    [JudgeBoard.SLDASM, JudgeBox.SLDASM, JudgeBoxCaseBottom.SLDPRT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]
2018-04-25 Exported STLs, updated cover fits in JudgeCover
    [JudgeBoard.SLDASM, JudgeBox.SLDASM, JudgeBoxCaseBottom.SLDPRT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]
2018-04-26 Updated taper on button sockets
    [TopButtonCover.SLDPRT, TopButtonCover.STL, TriggerButtonCover.SLDPRT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]
2018-04-26 Updated Trigger Button interferance fit
    [TriggerButtonCover.SLDPRT, TriggerButtonCover.STL]
2018-04-26 Updated Trigger Cover fit
    [TriggerButtonCover.SLDPRT, TriggerButtonCover.STL]
2018-04-26 Updated trigger button throw distance.
    [JudgeBoard.SLDASM, JudgeBox.SLDASM, JudgeBoxCaseBottom.SLDPRT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]
2018-04-27 Updated Main Box Case Center
    Allowed screws to be any length, modified clearances.
    [MainBox.SLDASM, MainBoxCaseBottom.SLDPRT, MainBoxCaseCenter.SLDPRT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]
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2018-04-28 Updated Top Button Tab Thickness.
    [TopButtonCover.SLDPRT, TopButtonCover.STL]
2018-05-04 Added unit test file
    [JudgeBoard.kicad_pcb, JudgeBoard.sch]
2018-05-04 Initial shift-register based judge controller schematic
    [JudgeBoard.sch]
2018-05-10 Updated symbols and footprints for pushbutton
    [BOM.ods, JudgeBoard.sch]
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2018-05-14 UPdated judge board layout
    [JudgeBoard.kicad_pcb, JudgeBoard.sch]
2018-06-07 Controller design iteration, code refactoring modifications
    [JudgeBoard.kicad_pcb]
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2018-06-17 Updated judge controller case.
    [JudgeBoard.SLDASM, JudgeBoxCaseBottom.STL, JudgeBoxCaseTop.SLDDRW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]
2018-06-18 Added libraries with customized components.
    [PiKwonDoHAT.kicad_pcb, PiKwonDoHAT.sch]
2018-06-19 Simplified judge controller schematic and pcb
    [JudgeBoard.kicad_pcb, JudgeBoard.sch]
2018-06-19 Added point values to button covers.
    [TopButtonCover.SLDPRT, TopButtonCover.STL, TopButtonCover1.SLDPRT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]
2018-06-19 Updatd button and judge box assembly.
    [JudgeBoard.SLDASM, JudgeBox.SLDASM, JudgeBoxCaseBottom.SLDPRT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]
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2018-06-20 Reduced judge board to 2 jumpers
    [JudgeBoard.kicad_pcb]
2018-06-20 Cleaned up judge controller PCB, removed 3 jumpers
    [JudgeBoard.kicad_pcb, JudgeBoard.sch]
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2018-06-21 Created HAT schematic and PCB
    [PiKwonDoHAT.sch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]
2018-06-24 Finalized HAT PCB design
    [PiKwonDoHAT.kicad_pcb, Timer.kicad_pcb, Timer.sch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]
2018-06-24 Updated trace routing on timer circuit
    [Timer.kicad_pcb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]
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2018-06-26 Updated BOM and component selection
    [BOM.ods]
2018-06-29 Updated Judge Board model and case.
    [JudgeBoard.SLDASM, JudgeBox.SLDASM, JudgeBoxCaseTop.SLDPRT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]
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2018-07-09 Added circuit protection elements to judge controller schematic
    [BOM.ods, JudgeBoard.sch]
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2018-07-12 Updated Judge PCB layout to include new footprints
    [JudgeBoard.kicad_pcb, JudgeBoard.sch]
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2018-07-13 Updated circuit protection elements to HAT schematic board.
    [BOM.ods, PiKwonDoHAT.kicad_pcb, PiKwonDoHAT.sch]
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2018-07-18 Updated CAM files for Timer and PCB for HAT
    [PiKwonDoHAT.kicad_pcb, PiKwonDoHAT.sch, Timer.kicad_pcb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]
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2018-07-22 Updated BOM and CAM files for HAT PCB
    [BOM.ods, PiKwonDoHAT.kicad_pcb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]
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2018-07-28 Tweaked and cleaned up hat schematic:
    * Made all input resistors 470 ohms
    * Cleaned up graphically
    * Reassigned reference numbers
    [PiKwonDoHAT.sch]
2018-07-28 Tweaked schematic a bit further; changed PCB references to match schematic.
    [PiKwonDoHAT.kicad_pcb, PiKwonDoHAT.sch]
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2018-07-29 Revert "Merge branch 'master' into electronics-tweaks; overwrite 'master' hat changes"
    This reverts commit 8490e2c3782f3b2eaf596155d8884dc6cd65858c, reversing
    changes made to 143268d8e254d2edd056497eb53e137ee58f0f7c.
    [BOM.ods, PiKwonDoHAT.kicad_pcb, PiKwonDoHAT.sch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]
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2018-07-29 Timer: Restore David's updated schematic and PCB from earlier failed merge.
    [Timer.kicad_pcb, Timer.sch]
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2018-07-29 Synchronized PCB with new netlist; cleaned up glitches.
    [Timer.kicad_pcb, Timer.sch]
2018-07-29 Timer: Rerouted to eliminate jumpers, at the cost of a few 1206's with two traces underneath.
    [Timer.kicad_pcb, Timer.sch]
2018-07-29 Timer: Increased C2 to 1 uF (per datasheet for U1 stability); brought RN1 back to 3.3 V instead of 5 V.
    [Timer.kicad_pcb, Timer.sch]
2018-08-22 Updated columns in BOM to allow copy and paste for mouser
    [BOM.ods]
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2018-09-04 Updated timer trace for proper clearance
    [Timer.kicad_pcb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]
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2018-09-13 Mirrored PCB across x axis for gcode generation
    [Timer.kicad_pcb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]
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2018-10-10 Corrected HAT board diode selection
    [BOM.ods]
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2018-10-12 Corrected component list for Timer board
    [BOM.ods]
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2018-10-23 Updating judge circuits and pcb to match timer
    [JudgeBoard.kicad_pcb, JudgeBoard.sch]
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2018-12-04 Updated tests for correct initialization.
    [pkd_timer.py, unit_test.py]
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2018-12-06 Updated to resolve bad merge.
    [MainBox.SLDASM, MainBoxCaseBottom.SLDPRT, MainBoxCaseBottom.STL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]
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2019-01-15 Corrected design error in Timer board, updated routing.
    [BOM.ods, ManufacturingDurations.ods, Timer.kicad_pcb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]
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2019-01-17 Intermediate commit while moving components to final locations.
    [JudgeBoard.kicad_pcb, JudgeBoard.sch]
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2019-01-19 Updated trace routing and board outline. Added mounting holes.
    [JudgeBoard.kicad_pcb, Timer.kicad_pcb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]
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2019-03-01 Updated to mate with RasPi Zero, reduced footprint significantly.
    [PiKwonDoHAT.kicad_pcb, PiKwonDoHAT.sch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]
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
